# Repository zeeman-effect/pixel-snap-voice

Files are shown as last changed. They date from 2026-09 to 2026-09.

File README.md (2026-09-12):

# pixel-snap-voice

A one-off slim rectangular **voice-note recorder** that snaps to the back of a **Google Pixel 10** using Pixelsnap / Qi2 magnets (MagSafe-style accessory rings work). It records raw WAV files, charges and dumps data over USB-C, and leaves transcription to a computer.

This repo holds hardware, firmware, simulation, and (later) a local transcription helper. The first board is meant to be ordered from quick-turn services after the sims pass — not invented from unsolved problems.

## What it is

- ESP32-S3-MINI-1U, **ES8311 codec** (I2S master), analog MEMS mic, class-D speaker (or headphone jack if thickness loses)
- 16-bit PCM WAV, **48 kHz** mono (~173 MB/hour)
- USB Mass Storage when plugged into a computer
- No on-device transcription, no Wi-Fi in v1, no wireless charging through the accessory

MCU choice and why we did **not** switch off Espressif: [`docs/audio-platform.md`](docs/audio-platform.md).

## Repo layout

| Path | Role |
| --- | --- |
| [`docs/architecture.md`](docs/architecture.md) | Electrical + mechanical constraints |
| [`docs/audio-platform.md`](docs/audio-platform.md) | Why ESP32-S3 + codec, not a different MCU |
| [`docs/bom.md`](docs/bom.md) | Living bill of materials |
| [`docs/manufacturing.md`](docs/manufacturing.md) | JLCPCB / print / CNC |
| [`docs/phase0-bringup.md`](docs/phase0-bringup.md) | Off-the-shelf DevKit path before a custom PCB |
| [`firmware/`](firmware/) | ESP-IDF app + portable recorder/WAV core |
| [`sim/host/`](sim/host/) | `HOST_SIM` HAL, tests, PC WAV fixture |
| [`sim/spice/`](sim/spice/) | USB → charger → battery → 3.3 V model |
| [`hardware/cad/`](hardware/cad/) | Parametric envelope (OpenSCAD) + keepout checker |
| [`hardware/kicad/`](hardware/kicad/) | KiCad 10 schematic / PCB / stackup notes |
| [`.cursor/skills/`](.cursor/skills/) | Agent skills, including vendored [KiStack](https://github.com/American-Embedded/kistack) KiCad workflows |
| [`software/`](software/) | Local whisper.cpp CLI (`transcribe.py`) |

## Simulate first

From the repo root, with CMake and a C compiler (MSVC, MinGW, or clang):

```bash
cmake -S sim/host -B build/host
cmake --build build/host
./build/host/recorder_test      # Windows: build/host/Debug/recorder_test.exe
./build/host/recorder_sim
```

Mechanical keepouts (Python 3, no extra packages):

```bash
python hardware/cad/check_envelope.py
```

Power path (needs [ngspice](https://ngspice.sourceforge.io/)):

```bash
ngspice -b sim/spice/power_path.cir
```

## Physical phases

0. Prove capture **and playback** on an Espressif voice board (Korvo-2 / ESP-BOX) or OpenMic; Sense is recorder-core only. See [`docs/phase0-bringup.md`](docs/phase0-bringup.md).
1. Custom slim PCB + 3D-printed chassis + bought magnet ring (JLCPCB).
2. Same PCB in CNC **6061 aluminum** (not steel).

After you change the product schematic sources, run `python hardware/kicad/recorder/generate_recorder.py` then `python hardware/kicad/recorder/verify_schematic.py`. That overwrites sheets only. It does not write `recorder.kicad_pcb`. Edit the board (or rebuild it on purpose with `generate_pcb.py`) until traces and DRC are clean. Do not order boards until `python scripts/check_gates.py` is clean **and** `kicad-cli pcb drc` is clean **and** `kicad-cli` has written Gerbers from `hardware/kicad/recorder/recorder.kicad_pcb`.

## Transcription

Dump WAVs over USB, then run a local model (whisper.cpp) on the computer:

```bash
python software/transcribe.py /path/to/recordings/20260828-181742.wav
```

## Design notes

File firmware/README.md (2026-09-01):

# Firmware

Portable recorder core in `core/` plus an ESP-IDF app that runs on:

| Board | Capture | Playback | SD | Notes |
| --- | --- | --- | --- | --- |
| ESP32-S3-Korvo-2 | ES7210 mics | ES8311 + NS4150 | 1-bit SDMMC | Phase 0 default. I2S clocks follow Espressif (S3 master). |
| ESP-BOX / BOX-3 | ES7210 | ES8311 + PA | none on the main unit | Use Korvo if you need on-board SD. |
| Custom PCB | ES8311 ADC | ES8311 DAC + NS4150 | 4-bit SDMMC | Codec is I2S master (12.288 MHz oscillator → MCLK). Pin map: `hardware/kicad/pinmap.md`. |

## Buttons

- **Short press** — start or stop a recording (`/recordings/YYYYMMDD-HHMMSS.wav`, 48 kHz 16-bit mono PCM)
- **Double press** — play the last file (press again to stop)
- **Long press (~1.5 s)** — deep sleep; wake on the same button (custom PCB)

A host MSC mount wins. Record and play stop, TinyUSB owns the card, no new recordings until unmount. 5 V on VBUS is not that event. Phase 0 with MSC off, or no card, keeps recording on USB power.

## Time

The S3 RTC resets on battery pull. After a USB dump, put `set_time.txt` at the volume root with one line, UTC `YYYY-MM-DD HH:MM:SS`:

```
2026-08-28 18:30:00
```

The app applies it on boot and after USB unmount, then deletes the file.

## Build

ESP-IDF v5.1 or newer (`esp_codec_dev` + TinyUSB):

```bash
cd firmware
idf.py set-target esp32s3
idf.py menuconfig   # Pixel Snap Voice → board
idf.py build
idf.py -p COMx flash monitor
```

Disable `CONFIG_PSV_USB_MSC` if you only want an SD reader for Phase 0.

Host-side tests (no IDF):

```bash
cmake -S sim/host -B build/host
cmake --build build/host
```

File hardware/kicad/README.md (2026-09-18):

# KiCad — custom slim PCB

4-layer **0.8 mm**, ENIG. Origin = magnet-ring center (same as CAD). USB is full speed and deliberately **not** impedance controlled — see [Stackup](#stackup-jlc-4-layer-08-mm).

Two trees only:

- **Product:** `recorder/` — schematic + PCB. Open `recorder.kicad_pro`.
- **Learning:** `example_project/` — hand-made KiCad 10 sandbox. Not product truth. Leave it alone unless you are in that lesson.

```bash
python hardware/kicad/recorder/generate_recorder.py
python hardware/kicad/recorder/verify_schematic.py
python hardware/kicad/recorder/route_pcb.py --planes-only   # needs pcbnew
python scripts/check_gates.py
```

`route_pcb.py` and `generate_pcb.py` need an interpreter that can `import pcbnew`. On Linux that is the system `python3`; on Windows use `%LOCALAPPDATA%\Programs\KiCad\10.0\bin\python.exe`.

`generate_recorder.py` overwrites the recorder sheets. It does not write `recorder.kicad_pcb`. `route_pcb.py --planes-only` loads that board and pours copper. It does not move parts. Close the recorder project in KiCad before running either script.

`generate_pcb.py` rebuilds the board from scratch and wipes copper. Run it only when you intend a placement reset, then pour and route again. `route_pcb.py` with no flag does the whole job: it clears copper, lays the planes, hand-routes the parts an autorouter cannot do (the USB-C escape, the D+/D− pair, the fine-pitch fanouts), locks them, hands the rest to freerouting over Specctra DSN/SES, then pours, stitches and repairs until `kicad-cli pcb drc` is clean. Footprint XY: [`recorder/placement.json`](recorder/placement.json). Keep it in sync with the board. CAD envelope is `hardware/cad/params.json` + `case.scad`. Those numbers can move when the case or board moves.

`check_gates.py` checks the files that are already on disk. It does not regenerate.

Sheets: `mcu_usb`, `audio`, `power`, `io` (global labels join them). Pin map: [`pinmap.md`](pinmap.md).

Before a fab upload, land patterns must be datasheet footprints, `kicad-cli pcb drc` must be clean, and `kicad-cli` must write `fab/` from `recorder.kicad_pcb`. `check_gates.py` now does the last two itself. SP1 is the KELIKING KLJ-01304T-08R07W land in `PSV.pretty`.

## Design rules

The board is checked against JLCPCB's published standard 4-layer FR-4 capability rather than a set of house numbers, so a green DRC means the fab can build it. Global floors are `DESIGN_RULES` in [`recorder/generate_pcb.py`](recorder/generate_pcb.py); each entry names the JLC figure it comes from and says where it is deliberately tighter. Two checks depend on what kind of item is involved and cannot be a single global minimum, so they live in [`recorder/recorder.kicad_dru`](recorder/recorder.kicad_dru): pad hole-to-hole spacing at 0.6 mm (JLC's floor is 0.45 mm; 0.6 mm keeps the plated-hole tolerance) and minimum non-plated hole (0.5 mm).

What the board actually holds, against what JLC allows:

| | Board | JLC standard |
| --- | --- | --- |
| Track width | 0.15 mm | 0.1016 mm |
| Via | 0.6 mm on a 0.3 mm drill | 0.25 mm on 0.15 mm |
| Pad hole-to-hole | 0.62 mm | 0.45 mm |
| Via hole-to-hole | 0.30 mm | 0.20 mm |
| Hole to copper | 0.30 mm | 0.20 mm |
| Copper to routed edge | 0.30 mm | 0.20 mm |
| Silk text | 1.0 mm on a 0.15 mm stroke | 1.0 mm on 0.15 mm |

Hole-to-copper is held at 0.3 mm rather than JLC's 0.2 mm because non-plated holes carry a ±0.2 mm diameter tolerance: a 1.7 mm mounting hole can come back 0.1 mm larger in radius and eat the difference. The same margin is what forced MK1's ring pad outward, since the stock Infineon land leaves only 0.18 mm to the sound port.

## Stackup (JLC 4-layer 0.8 mm)

| Layer | Role | Copper |
| --- | --- | --- |
| F.Cu | signals, tall parts (battery side) | 1 oz |
| prepreg | ~0.10 mm | |
| In1.Cu | GND plane | 0.5 oz |
| core | ~0.53 mm | |
| In2.Cu | **VDD33** pour | 0.5 oz |
| prepreg | ~0.10 mm | |
| B.Cu | GND, **flat toward the shunt / phone** | 1 oz |

USB pair: 0.20 mm traces on a 0.40 mm pitch, F.Cu over the solid In1 GND plane. **Not impedance controlled, and no controlled-impedance option needs ordering.** The ESP32-S3 USB peripheral is full speed only (12 Mbps, no high-speed PHY), and 90 Ω on this 0.1 mm top prepreg would need roughly 0.06 mm traces, half what a quick-turn fab will run. The geometry above lands near 75 Ω differential by first-order microstrip, which is fine at full-speed edge rates. If a later revision ever needs high-speed USB, thicken the top prepreg first.

The pair is long for USB. That is placement, not sloppiness: U1's USB pads sit on the module's top row, the far side of a 15.9 mm module from J2, and the castellations leave 0.05 mm between pads, so the pair has to go around the module rather than under it. It runs up the 3.3 mm channel between J1 and U1. The millimetres used to be typed here too. They are measured off the board by `route_pcb.py` and written to [`recorder/placement.json`](recorder/placement.json) under `routing.usb`; read them there, because a copy in prose goes stale the first time anyone reroutes.

## Keepouts

- No tall parts on B.Cu (phone / shunt side)
- Mic on the right long edge, away from U4 / U5
- USB-C (**J2**) on the bottom short edge, offset +8 mm
- JST-PH battery (**BT1**) on the top-left, land `JST_PH_S2B-PH-K`. USB-C is the only 5 V inlet
- Analog island (U2, U8, MK1, Y1) off **VDD33**
- Analog footprint centres off the magnet circle; SP1 also by courtyard, because the 13 mm can holds a magnet (`check_placement.py`)
- PA LC away from the magnet circle (comment layer)
- MINI-1U module (15.4 × 15.4 mm). No PCB-antenna keepout. IPEX unpopulated
- 4× M1.6 holes. No fiducials on this first pass.

Gerbers: `fab/` after `scripts/check_gates.py`, which runs `kicad-cli pcb drc` first and then writes the Gerbers, both drill files, the pick-and-place CSV, `recorder-jlc.zip` and the JLCPCB CSVs (`jlcpcb_bom.csv`, `jlcpcb_cpl.csv`, `jlcpcb_extra.csv`, via [`recorder/generate_jlc.py`](recorder/generate_jlc.py)) in one pass from `recorder.kicad_pcb`. Do not hand-export or hand-edit only part of that set: a drill file that does not match the copper is a scrap board, and a pick-and-place row that does not match it is a misassembled one. Both CSVs were hand-kept until four decoupling capacitors were found still sitting at their pre-route coordinates. The gate runs DRC at every severity and with `--schematic-parity`, then runs it again with `--refill-zones` and refuses to plot if the answers differ — `kicad-cli` plots the fill stored in the board, so a stale pour would ship while DRC quietly refilled and passed it.

Open `recorder/recorder.kicad_pro` in KiCad 10. ERC/DRC in KiCad is the last human glance. The Python checks are the repo gate.

U1 comes from `hardware/cad/params.json` `mcu`. Change the module there, then update the recorder schematic sources and regenerate the sheets.

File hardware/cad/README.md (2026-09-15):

# CAD envelope

OpenSCAD and `params.json` must stay twins. `params.json` and `params.scad` share the same Pixel 10 + magnet-ring numbers. Change a number in both files. `check_envelope.py` fails if they drift, if the accessory hits a keepout, if the lid battery fence hits SP1 or U1, or if the speaker grille XY drifts from `placement.json` SP1.

```bash
python hardware/cad/check_envelope.py
openscad -o hardware/cad/case.stl hardware/cad/case.scad   # PETG
```

## Current defaults (caliper before CNC)

| Item | Value |
| --- | --- |
| Pixel 10 body | 152.8 × 72.0 × 8.6 mm |
| Camera bar | 24 mm from top, full width (measure) |
| Pixelsnap center | 85 mm from top, 36 mm from left (measure) |
| Magnet ring | OD 56 / ID 44 / 1.1 mm + 0.3 mm steel shunt |
| Accessory | 67 × 90 × 9 mm |
| PCB | 64 × 86 × 0.8 mm, 4-layer |

Print the magnet pocket slightly loose (`pocket_extra` in `case.scad`), shim, then tighten after the real ring arrives. Chassis is PETG first, 6061 later — not steel.

Shared origin, heights, and the PETG-on-Pixel checklist: [`INTERFACE.md`](INTERFACE.md).

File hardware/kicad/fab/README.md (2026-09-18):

# Fab export

`python scripts/check_gates.py` writes this whole folder from `hardware/kicad/recorder/recorder.kicad_pcb`, in one pass, after running `kicad-cli pcb drc`. It needs `kicad-cli`: on Linux that is on PATH, on Windows it is `%LOCALAPPDATA%\Programs\KiCad\10.0\bin\kicad-cli.exe`.

Contents: Gerbers, PTH/NPTH Excellon drills and their map PDFs, `recorder-pos.csv` (pick and place), and `recorder-jlc.zip`. The zip holds the copper, mask, silk, outline and drills only — the Fab, Courtyard, Adhesive, Margin and User layers are internal documentation and JLCPCB should not see them. BOM/CPL/extra sit one level up: `jlcpcb_bom.csv`, `jlcpcb_cpl.csv`, `jlcpcb_extra.csv`.

Never hand-export part of this set. These files only mean anything together: an earlier version of the gate script refreshed the Gerbers but left the drill file at whatever date it was committed with, which described a board with none of its vias drilled.

JLC order: 4-layer, 0.8 mm, ENIG. **No controlled impedance** — USB here is full speed and the pair is deliberately uncontrolled. Everything else is standard capability too: 0.15 mm minimum trace, 0.6 mm vias on a 0.3 mm drill, standard-font silkscreen. Nothing here should trigger a fine-line, small-via or high-precision-legend surcharge. See `hardware/kicad/README.md`.

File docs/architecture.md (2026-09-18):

# Architecture

One-off Pixelsnap-compatible voice recorder. Copy known ESP32-S3 + codec + LiPo + USB MSC patterns. Do not invent wireless charging through the shell or on-device ASR. MCU vs codec rationale: [`audio-platform.md`](audio-platform.md).

## System

```
Pixel 10 (Pixelsnap / Qi2 magnets)
        |
   magnet ring + steel shunt  (accessory side)
        |
  analog MEMS --> ES8311 ADC --I2S--> ESP32-S3 --FAT--> microSD
  speaker/HP  <-- ES8311 DAC + PA     |                    |
                         USB 2.0 device              USB MSC
                                |
                    USB-C 5 V sink + CC 5.1k
                                |
                         BQ24074 power-path
                           |           |
                         VSYS        VBAT (pouch)
                           |
                    3.3 V digital + 2.8 V analog LDO
```

ES8311 is the **I2S master** (12.288 MHz oscillator into MCLK). The S3 is slave. Analog AVDD for the codec and the MEMS mic is a separate 2.8 V LDO (U8 LP5907-2.8, net **3V3A**) from the MCU 3.3 V rail (U4 AP2112 + U5 AP22804, net **VDD33**). The analog rail is 2.8 V because IM73A135 VDD abs max is 3.0 V; ES8311 AVDD is 1.7–3.6 V. A buck is preferred for battery life; this spin uses the LDO.

When USB is plugged in: stop recording, expose `/recordings` as a USB Mass Storage volume, charge. When idle: deep sleep, button wake.

## Solved references

- Firmware / WAV-to-storage / USB mount: [ESP32-OpenMic](https://codeberg.org/RevK/ESP32-OpenMic)
- Early bring-up: ESP32-S3-Korvo-2 / ESP-BOX (ES8311 + analog mic + PA); Sense is recorder-core only
- Magnet geometry: MagSafe accessory array / Qi2 MPP ring (commodity rings), not a custom magnet design

## Electrical

| Block | Choice | Notes |
| --- | --- | --- |
| MCU | ESP32-S3-MINI-1U (≥8 MB flash) | Native USB. Same pins as MINI-1, 15.4 × 15.4 mm, no PCB antenna. **Not** the audio bottleneck. |
| Codec | Everest ES8311, I2S master, 12.288 MHz oscillator → MCLK | PGA/ALC/ADC + DAC + HP. Dedicated analog LDO (U8). No XI/XO on this codec. |
| Mic | Analog MEMS: IM73A135 (~73 dBA) | Pin 3 is OUT−, left open; C15 couples OUT+. VDD 2.8 V. Fallback: ICS-43434 I2S (65 dBA). **INMP441 is EOL.** |
| Playback | NS4150B into KELIKING KLJ-01304T-08R07W (13 mm SMD, LCSC C18186315) | 8 Ω 0.7 W can JLC can place. If 9 mm loses: 3.5 mm jack on ES8311 HP |
| Storage | Low-profile microSD (FAT32) | Switch to eMMC only if CAD proves SD is too thick |
| USB-C | 5 V sink only, 5.1 kΩ CC1/CC2 pulldowns, USB 2.0 | No USB-PD. USB-C is the only 5 V inlet |
| Charge | BQ24074RGTR, USB500 ~500 mA (EN1/EN2, ISET 1.8 kΩ) | Power-path: **VSYS** = OUT (loads), **VBAT** = pouch only. Charge LED on STAT. No fuel gauge |
| 3.3 V | Buck preferred (efficiency); LDO this spin (U4 AP2112 + U5 AP22804 → **VDD33**) | U4 VIN from **VSYS**. Keep the regulator and any later switching node away from the mic |
| Battery | Single-cell LiPo pouch on JST-PH BT1 | Size from leftover volume. Buy a protected 1S pouch; this board has no pack protector |
| Controls | 1 user tactile (SW1): short = record, double = play last, long = sleep. Two prototype flash buttons (SW_BOOT, SW_RST), lid-off only | 1 LED: record / play / charge / error |
| RF | MINI-1U IPEX, no cable in v1 | A PCB antenna would sit next to a steel shunt and later an aluminum shell. Wi-Fi off in firmware. |

### Audio format

- Container: WAV (RIFF)
- Encoding: PCM, 16-bit signed little-endian
- Rate / channels: **48 kHz**, mono (16 kHz sounds telephone-narrow on playback; codecs expect 48 k)
- Path: `/recordings/YYYYMMDD-HHMMSS.wav`
- Size: 48000 × 2 bytes/s = **96 kB/s ≈ 173 MB/hour** → ~46 hours on 8 GB
- Do not store 24-bit files; 16-bit already exceeds a 65–74 dBA capsule. Keep 24-bit on the I2S wire if the mic provides it.

### Power budget (v1 estimate)

MCU-only 126 mA was optimistic. With codec and SD, PA off, the working number is about 160 mA from the cell. Current pouch is **500 mAh** from leftover CAD volume (~3.1 h). Change the pouch if leftover volume or measured current changes. Re-measure on the SMT board. Idle deep-sleep is dominated by the charger IC and any always-on LDOs. Keep a true load switch on the 3.3 V rail.

### USB-C

- CC1 and CC2 each 5.1 kΩ to GND (UFP / sink)
- VBUS to charger IN through a PTC. USB-C is the only 5 V inlet.
- **BT1** is a JST-PH (`S2B-PH-K-S`, land `JST_PH_S2B-PH-K`) for a 1S pouch on VBAT. Do not put 5 V on BT1. Do not strap **VSYS** (charger OUT) to VBAT. C21 (10 µF) sits on VBAT next to U3 so BAT has local ceramic when BT1 is open.
- D+/D− to ESP32-S3 USB PHY (or USB-Serial/JTAG pins per module datasheet)
- Do not implement PD sink for v1

## Mechanical — Pixel 10 + Pixelsnap

Sources: GSMArena / Google store for body size; WPC Qi2 / MagSafe accessory practice for the ring. **Magnet center on the Pixel 10 must be calipered** before a metal shell is cut; CAD parameters live in [`hardware/cad/envelope.scad`](../hardware/cad/envelope.scad).

| Item | Value | Status |
| --- | --- | --- |
| Phone body | 152.8 × 72 × 8.6 mm | Published |
| Camera bar extra thickness | ~3.4 mm | Published (Pixel 9-class bar; confirm on device) |
| Camera bar length along height | parameterized, default 24 mm from top | **Measure** |
| Qi2 / MagSafe accessory ring | OD ~56 mm, ID ~44 mm, thick ~1.0–1.2 mm | Commodity part |
| MagSafe accessory array (Apple-style) | often OD 54 × ID 46 × 1.1 mm | Accept either; pocket to the part you buy |
| Steel shunt | thin plate **behind** the ring (away from the phone) | Required for hold strength |
| Accessory envelope (v1 target) | 67 × 90 × 9 mm | Current numbers in `hardware/cad/params.json`. Edit them if the case needs to move. |
| Pixelsnap center | 85 mm from top, 36 mm from left | **Caliper before CNC** |
| Chassis | 3D-print first; CNC **6061 aluminum** later | **Not steel** — steel shorts the magnetic path |

### Stack (phone glass → outside)

1. Magnet ring + adhesive
2. Steel shunt
3. PCB (MCU, codec, mic, PA, USB-C, SD)
4. LiPo pouch
5. Back shell (plastic proto / 6061)

### Keepouts (enforced by `hardware/cad/check_envelope.py`)

- Accessory outline must **not overlap the camera bar** in the XY plane when snapped.
- USB-C on a **short edge**; overmold keepout must not intersect the phone body.
- Mic acoustic port on a **free long edge**, not into the glass, or recordings go muffled.
- Magnet ring must stay inside the accessory outline.
- Analog codec island and mic bias stay off **VDD33**; PA LC/ferrite away from the magnet ring.

### Metal / magnets / OIS

Use an **aluminum or plastic** shell. Put ferromagnetic material only as the designed shunt behind the ring. The phone already expects a MagSafe-style ring at the Pixelsnap location; do not add extra magnets near the camera bar (OIS / magnetometer).

## Firmware split

Portable core (`firmware/core`) builds two ways:

- `HOST_SIM` — POSIX files, fixture WAV or generated PCM, tests in `sim/host`
- `ESP_PLATFORM` — ESP-IDF `app_main`, ES8311 duplex I2S (`esp_codec_dev`), SD, USB MSC, deep sleep

State machine: `IDLE` → `RECORDING` or `PLAYING` → `IDLE`. A host **MSC mount** forces `USB_MSC` (record and play stop). VBUS alone does not. No card, or `CONFIG_PSV_USB_MSC` off, means USB power does not take the card.

## Out of scope

- On-device transcription
- Wi-Fi
- Charging the phone through this accessory
- MagSafe / Qi2 certification
- Waterproofing
- Android app while snapped on (USB-OTG geometry is awkward)

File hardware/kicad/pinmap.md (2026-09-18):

# Custom PCB pin map

Human table. Matches `firmware/boards/custom.h` and `hardware/kicad/recorder/` refs.
Not generated. Origin and heights: [`../cad/INTERFACE.md`](../cad/INTERFACE.md). Footprint XY: [`recorder/placement.json`](recorder/placement.json).

U1 is ESP32-S3-MINI-1U-N8 (`params.json` `mcu`). ES8311 is I2S **master**; S3 is slave.
Y1 is a 12.288 MHz oscillator into ES8311 **MCLK**. The codec has no XI/XO pins.
Strapping GPIO0 / GPIO45 / GPIO46 are not used as I2S or SD.

## ESP32-S3-MINI-1U-N8

| GPIO | Net | Direction | Goes to |
| --- | --- | --- | --- |
| 3V3 / GND | **VDD33** / GND | power | U5 AP22804 / pour |
| GPIO19 / GPIO20 | USB_DM / USB_DP | USB PHY | U7 USBLC6-2, **J2** |
| GPIO4 / GPIO5 | I2C_SDA / I2C_SCL | open-drain | U2 ES8311 CDATA / CCLK |
| GPIO14 | I2S_MCLK | input | U2 MCLK + Y1 out |
| GPIO13 | I2S_BCLK | input | U2 BCLK |
| GPIO12 | I2S_WS | input | U2 LRCK |
| GPIO10 | I2S_DIN | input | U2 ASDOUT |
| GPIO11 | I2S_DOUT | output | U2 DSDIN |
| GPIO8 | PA_EN | output | U6 NS4150 CTRL |
| GPIO15 | SD_CLK | output | **J3** |
| GPIO7 | SD_CMD | bidirectional | **J3** |
| GPIO6 / 16 / 17 / 18 | SD_D0–D3 | bidirectional | **J3** 4-bit SDMMC |
| GPIO0 | BOOT | strapping, pull-up | SW_BOOT to GND (download, lid-off). Not a firmware button |
| GPIO1 | BTN | input, pull-up | SW1 to GND |
| GPIO2 | LED | output | D1 |
| GPIO9 | CHG_STAT | input | U3 STAT (D2 charge LED on this net) |
| GPIO43 / GPIO44 | UART_TX / UART_RX | UART0 | **J1** 1×4 (3V3, U0RXD, U0TXD, GND) |
| EN | EN | module enable | R1 10k / C2 plus **SW_RST** to GND |

## Other

| Net | Notes |
| --- | --- |
| CC1 / CC2 | R2 / R3 5.11 kΩ to GND (UFP) on J2 |
| **VDD33** | U4 AP2112 → U5 AP22804. MCU digital rail |
| 3V3A | U8 LP5907-2.8 from **VSYS** (~2.8 V); star return to AGND; no digital return through MK1. Named 3V3A; it is not 3.3 V |
| VBAT | LiPo pouch on BT1; U3 BQ24074 BAT plus C21 at the QFN. Do not strap to VSYS |
| VSYS | U3 OUT. USB or cell, whichever is up. Feeds U4, U8, U6 |
| RF | MINI-1U IPEX connector, no cable in v1 |

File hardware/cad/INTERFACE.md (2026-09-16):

# CAD ↔ PCB interface

One origin, one height map. If a number moves, change CAD and the board together. Do not leave a second copy only in KiCad.

## Origin

Phone-facing view of the accessory.

- **(0, 0)** = center of the magnet ring = Pixel Pixelsnap axis
- **+X** = phone right
- **+Y** = toward the camera bar (phone top)
- **+Z** = away from the glass (out of the phone)

The KiCad board origin matches. Edge.Cuts is the 64 × 86 mm PCB, not the 67 × 90 mm shell.

## Height map (phone glass → outside)

| Layer | Z span (mm) | Notes |
| --- | --- | --- |
| Adhesive | 0.00–0.15 | Ring stock / VHB, phone-facing |
| Magnet ring | 0.15–1.25 | Ferromagnetic only here + shunt |
| Steel shunt | 1.25–1.55 | Behind the ring, away from the phone |
| PCB | 1.55–2.35 | 0.8 mm; **B.Cu** is the flat phone-facing side |
| Tray / lid split | 2.35 | `tray_h` = adhesive + magnet + shunt + PCB = 2.35 mm. `lid_h` = 6.65 mm |
| Tall parts | 2.35–5.55 | USB-C 3.2 mm, module 2.4 mm, SD on **F.Cu**. In the lid |
| LiPo pocket | 2.35–7.35 | 5.0 mm pouch at (0, 10), +Y of U1/J2 and −Y of SP1 |
| Speaker (SP1) | 2.35–6.35 | 4.0 mm KELIKING can on F.Cu. Sound faces the lid |
| Back shell | 7.80–9.00 | 1.2 mm PETG (`shell_back`). `speaker_grille()` opens the skin over SP1 |

Envelope budget is **9.0 mm**. USB stack is 6.75 mm. Speaker stack is 7.55 mm. Battery stack is 8.55 mm.

`case.scad` puts a 0.4 mm PETG floor under the magnet ring so it cannot fall through. That floor is a print trick. It does not change the stack numbers in `params.json`. Edit those if the stack changes. After the real ring arrives, shim, then tighten the pocket.

The tray also leaves a 0.5 mm PETG floor on the phone face under MK1. A 3 mm collector under the B.Cu NPTH at (30.00, 9.32) and a 3 mm channel in +X take that hole out the right wall, where it joins `mic_port()`. MK1 is on F.Cu. A port that faces the glass muffles recordings. If you move MK1, move the duct and the wall hole with it.

SW_BOOT / SW_RST are 5.1 × 5.1 × 5.0 mm top-actuated parts on F.Cu. Lid cavity above the PCB is 5.45 mm, so the actuators sit 1.65 mm under the outer skin. **Lid-off only** this spin: a flush hole in 1.2 mm PETG does not reach them.

## XY locations (magnet-centered)

Edge features are the wall or board edge (PCB is 64 × 86 mm, so the long edges are ±32 mm and the short edges are ±43 mm). Footprint centers are inset.

The official board is `hardware/kicad/recorder/recorder.kicad_pcb`. Footprint XY lives in `hardware/kicad/recorder/placement.json`.

The table below is the CAD wall-cut contract from `params.json`. Change the case cuts when you move a part or caliper a phone and a stuffed board.

| Feature | X (mm) | Y (mm) | Max Z above PCB |
| --- | --- | --- | --- |
| USB-C edge / overmold | +8.0 | −45.0 (accessory bottom wall) | 3.2 mm (F.Cu) |
| USB-C footprint (J2) | +8.0 | −37.6 | 3.2 mm (F.Cu). Mouth at y=−43. Rectangular wall slot this pass |
| Mic port (wall) | +33.5 (right long wall) | +10.0 | 3 × 2 mm hole at the tray/lid split (`mic_port()`). Tray `mic_duct()` joins this hole. |
| Mic capsule (MK1) | +30.0 | +10.0 | IM73A135 on **F.Cu**, rot 90°. Bottom-port NPTH is at (30.00, 9.32) on **B.Cu**. Port must not face glass. The tray ducts that hole under the PCB to the right wall. |
| Button edge | −33.5 (left long wall) | +12.0 | 3 × 2.2 mm press-through slot (`button_hole()`). Needs a moulded nub to span the 0.9 mm from the inner wall face to the actuator tip. |
| Button (SW1) | −29.3 | +12.0 | side-actuated Panasonic EVQP7C01P, rot 270° so the actuator faces the left wall. Tip 0.6 mm inside the board edge; copper 1.46 mm off it. |
| LED (D1) | −29.0 | +18.0 | side window in the lid wall, not through the back |
| SD slot (J3) | see placement.json |  | no mouth in this pass |
| Speaker (SP1) | 0.0 | +36.0 | 4.0 mm KELIKING KLJ-01304T on F.Cu. Sound faces the lid; `speaker_grille()` opens the back skin |
| JST-PH (BT1) | −23.5 | +34.0 | S2B-PH-K-S, 6.0 mm tall. Pad 1 (VBAT) at this XY; cable toward y=+43. `jst_window()` cuts shell_back over the housing |
| LiPo pocket | 0.0 | +10.0 | 40 × 30 × 5 mm pouch. Lid `battery_fence()` outer is 43.6 × 33.6 mm around this. Was y=12; that put the +Y wall 0.7 mm from SP1. |
| MCU module (U1) | +14.0 | −18.0 | 2.4 mm, next to USB; MINI-1U, IPEX unused |
| Mounting holes | ±(32−3.5), ±(43−3.5) | M1.6 clearance |

### Recorder designators

These are the recorder project names. Do not keep the old generated-board map.

| Ref | What |
| --- | --- |
| J2 | USB-C receptacle |
| J3 | microSD |
| J1 | UART header |
| U8 | analog LDO (codec / mic) |
| VDD33 | MCU 3.3 V rail |
| U1 | ESP32-S3-MINI-1U |
| BT1 | JST-PH S2B-PH-K-S (pad 1 at −23.5, 34) |

Export KiCad STEP (`File → Export → STEP`) and import next to `case.scad` (OpenSCAD cannot import STEP; use the STL from `case.scad` plus the KiCad 3D view, or Fusion/Onshape for a boolean). `check_envelope.py` is the automated gate; a 3D collision pass is visual.

## PETG print fit on a Pixel 10

`case.scad` already lays the two parts on one plate: tray at the origin, lid shifted +X.

1. Print in PETG. Tray sits phone-face down. Lid sits mating-face down (the rabbet groove is on the bed).
2. Magnet pocket is 0.3 mm loose on OD. Drop in the bought ring + steel shunt (shunt **behind** the ring, away from the phone). Shim with tape. Do not chase a tight magnet until the real ring is on the desk. Isolate the shunt from any later metal lid with tape.
3. M1.6 screws. `hole_d` 1.7 mm and the boss bore are **clearance**, not a tap. Do not thread PETG. Nuts or heat-set inserts come later. Keep screw heads off the phone glass.
4. Drop in a dummy PCB (or the first fab) and a 5 mm dummy pouch. The pouch pocket is 40 × 30 × 5 mm at (0, 10), clear of U1, J2 and SP1. Confirm the lid grille sits over the speaker and the fence wall does not hit the can.
5. Snap to the Pixel. Confirm:
   - camera bar not covered
   - USB-C cable overmold misses the phone
   - mic port is on the long edge, not against glass
   - button reachable while snapped
   - snap hold feels OK (add or remove tape shims)
   - tray and lid still locate on the lip after a few open/close cycles
6. Only then order SMT, or order PCB+SMT in parallel if this 3D check is clean and you accept a spin.

Assembly order: ring adhesive on glass side → ring → shunt → PCB (flat to shunt) → pouch → lid. Screws plus the mating lip hold it. No snap-fit this pass.

Pixel body and Pixelsnap center stay the published defaults until you caliper a real phone. **Caliper before any 6061 toolpath.** Chassis is PETG first, then 6061, never steel.

## If 9 mm loses

SP1 is a 4.0 mm SMD can. The speaker stack is 7.55 mm under a 9.0 mm envelope. If a stuffed board still blows the stack, use the ES8311 3.5 mm jack and drop the PA. That decision belongs at this height-stack check, not after fab.

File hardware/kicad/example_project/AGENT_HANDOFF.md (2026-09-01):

# Learning schematic handoff

Continue a supervised KiCad 10 schematic lesson. Zach is drawing `hardware/kicad/example_project` by hand to compare later with `hardware/kicad/recorder/`. He does the edits. You review, correct, and give **one** next step. Do not make large unsupervised edits. Fix a section only when he asks.

This file is the brief. Do not load the full prior chat.

## Overrides

Workspace rule says do not edit `example_project`. **This lesson overrides that.** You may read and, with his OK, make small fixes there.

Do **not** edit the product tree `hardware/kicad/recorder/` as part of this lesson. Compare his sheet to `recorder/` for refs and nets. Do not treat `recorder/` as a pin-for-pin copy-paste template. Architecture truth: `docs/architecture.md`, `docs/audio-platform.md`, `docs/bom.md`, `hardware/kicad/pinmap.md`, `hardware/cad/params.json` (`mcu` = ESP32-S3-MINI-1U-N8, no radio, no PCB antenna).

v1: USB recorder, 5 V sink only, no OTG host, no PD, no Wi-Fi.

Be brief. Plain language. Define a term once. Conserve chat context: review the `.kicad_sch` (or `.history` if newer) instead of dumping sheets into the thread.

## How he works

- KiCad 10. Schematic: `hardware/kicad/example_project/example_project.kicad_sch`
- **Toolbar Save works. Ctrl+S often does not.** Check Hotkeys → Save. Local history (`.history/example_project.kicad_sch`) can be newer than the project file. If the repo file looks stale, read history and tell him to Save.
- `Q` is Place → no-connection flag, not a symbol named Q.
- Net labels (`L`) name a net only if they sit on a wire. Generic connector pin names are hidden in the library; he cannot rename `Pin_1` from properties.
- Power symbol **Value** is the net name (`VDD33`, `VBUS`, `VBUS_CHG`, `VBAT`). `Earth` ≠ `GND`.
- ERC `pin_not_connected` on unused GPIOs is expected. Do not `Q` pins he will use later (I2C, I2S, SD, button, LED).
- ERC `power_pin_not_driven` on named rails is expected until a regulator or `PWR_FLAG` exists. Do not fake-fix with `PWR_FLAG` unless you are teaching that on purpose.

## What is on the sheet (as of 2026-08-30)

**MCU**

- U1 `ESP32-S3-MINI-1` symbol, value `ESP32-S3-MINI-1U`, footprint `PCM_Espressif:ESP32-S3-MINI-1U`. Correct pairing (same pins, IPEX on module).
- Pin 3 `3V3` → `VDD33`. Stacked GND → `GND`.
- EN RC: R1 `10K`, C2 `1 µF` (datasheet §9 / Fig 9-1).
- C1 `22 µF` + C3 `0.1 µF` on `VDD33`.
- J1 UART 1×4: pin1 `3V3`, pin2 U0RXD (GPIO44), pin3 U0TXD (GPIO43), pin4 `GND`. Labels `UART_TX` / `UART_RX` plus adapter TX/RX notes. MCU TX → adapter RX.

**USB-C (J2)**

- `Connector:USB_C_Receptacle_USB2.0_16P` (keep 16P; 14P drops SBU only). Not a Plug.
- GPIO20 → D+ (A6 shorted to B6). GPIO19 → D− (A7 shorted to B7). Labels `USB_DP` / `USB_DM` on the wires (~x=233).
- CC1 and CC2 each have their own `5.11k` (R2, R3) to `GND`. Not tied together.
- SBU1 / SBU2 unused. Shield still open (OK).
- Do **not** copy Fig 9-1 OTG (no ID pin, no host VBUS out). USB-C role is CC pulldowns.

**5 V / charger** (confirmed with `kicad-cli sch export netlist`, not raw coordinates)

- J2 A4/A9/B4/B9 VBUS → F1 pin 2. F1 pin 1 → `VBUS_CHG` → C4 pin 1 and U2 pin 4 `V_{DD}`.
- U2 `MCP73831-2-OT` (BOM U3 / `MCP73831T-2ACI/OT`). VSS pin 2 → `GND`. PROG pin 5 → R4 `2k` → `GND`.
- C4 `4.7 µF` on `VBUS_CHG` to `GND`. C5 `4.7 µF` on `+BATT` to `GND`.
- The old short at `(250.19, 44.45)`–`(250.19, 48.26)` is gone. `+BATT` ≠ `VBUS_CHG`.
- `#PWR010` is `power:+BATT`, Value `+BATT`. That net is U2 pin 3 `V_{BAT}` + C5. Electrically right. Rename Value to `VBAT` so the rail matches the lesson names.
- STAT pin 1 is open. ERC `pin_not_connected` at `(276.86, 58.42)`. Put `Q` until the LED.

Do not infer U2 pin nets from file coordinates. `kicad-cli` is `%LOCALAPPDATA%\Programs\KiCad\10.0\bin\kicad-cli.exe`.

## Open defect

None that blocks new parts. Optional cleanup: Value `+BATT` → `VBAT`, and `Q` on STAT.

## Suggested next steps (one at a time)

1. Rename `+BATT` to `VBAT`, `Q` on STAT. Then the 2-pin battery connector: `VBAT` and `GND`. Not to `VDD33`.
2. Battery connector (2-pin): `VBAT` and `GND`. Not to `VDD33`.
3. MCU 3.3 V LDO (BOM U4 `AP2112K-3.3`): VIN from `VBAT` (through load switch later), VOUT = `VDD33`. This clears the “magic 3V3” rail. Do not feed the LDO from raw VBUS.
4. Load switch (BOM U5 AP22804) on 3.3 V if you want sleep current next.
5. USB ESD `USBLC6-2SC6` on D+/D−, or analog 3V3A LDO (recorder: U8 LP5907), then ES8311. Codec is I2S **master**, 12.288 MHz oscillator into MCLK. Pin map: `hardware/kicad/pinmap.md`.
6. Leave IPEX unused (no cable in v1).

Do not start the codec until `VDD33` is generated from `VBAT` and the three rails stay separate: **5 V USB / ~4.2 V cell / 3.3 V MCU**.

## KiCad facts he already hit

- MINI-1 vs MINI-1U: same pin table. 1U is IPEX, no board antenna pin.
- Table 3-1: pin 3 only `3V3`; many stacked GND; EN must not float; USB_D− = GPIO19, USB_D+ = GPIO20. S3 PHY, no 22 Ω series.
- 16P has separate A6/B6 and A7/B7. Short same-name pairs or a flipped cable has no data.
- MCP73831 needs ≥4.7 µF on VDD and on VBAT.

## Style

Review what he drew. Name concrete nets and pins. One next action. No recorder-sheet copy-paste. No large refactors.

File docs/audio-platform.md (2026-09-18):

# Audio platform (MCU + codec)

**Current pick is the ESP32-S3.** Pair it with a real codec and a better capsule. Switching MCU throws away USB-MSC + ESP-IDF already in this repo and does not raise capsule SNR. Do it only if leaving Espressif is a hard requirement.

The S3 is not the hiss or the missing speaker. The original BOM recorded from a ~65 dBA digital MEMS and had **no DAC or amp**. nRF, STM32, RP2350, and i.MX RT cannot raise ICS-43434 SNR, and they throw away USB-MSC + ESP-IDF already in this repo.

## Bottlenecks (in order)

1. **No playback path** — MEMS → I2S → MCU cannot drive a speaker or headphone.
2. **The microphone’s own ADC** — [ICS-43434](https://cdn.sparkfun.com/assets/a/9/c/9/1/DS-000069-ICS-43434-v1.2.pdf) is 65 dBA SNR. The converter lives in the capsule.
3. **Power / layout** — analog mics and codec ADCs die if they share a noisy 3.3 V buck. Give the codec a dedicated analog LDO.
4. **ESP32-S3 has no APLL** — 48 kHz from the 160 MHz PLL is slightly inexact. Fix: **ES8311 is I2S master** with a 12.288 MHz oscillator into MCLK; the S3 is slave. ~0.1% pitch error is inaudible for voice notes. The codec has no XI/XO pins.

USB full-speed is enough to dump 48 kHz / 16-bit mono (~96 kB/s). Wi-Fi stays off. Use the MINI-1U module (IPEX, no cable), not the MINI-1 PCB-antenna sibling. The antenna keepout and extra 5.1 mm of module length buy nothing on a radio-off board that sits on a steel shunt.

This product already exists: [ESP32-OpenMic](https://codeberg.org/RevK/ESP32-OpenMic) (S3 module + ICS-43434 + MAX98357A + USB MSC). Espressif voice boards use **ES8311 + analog mic + class-D**, not a different SoC: [ESP32-S3-Korvo-2](https://docs.espressif.com/projects/esp-adf/en/latest/design-guide/dev-boards/user-guide-esp32-s3-korvo-2.html), IDF [`i2s_es8311`](https://docs.espressif.com/projects/esp-idf/en/stable/esp32s3/api-reference/peripherals/i2s.html), [`esp_codec_dev`](https://components.espressif.com/components/espressif/esp_codec_dev).

## Default (v1 custom PCB)

ESP32-S3-MINI-1U + **ES8311 as I2S master** (12.288 MHz oscillator → MCLK) + analog MEMS (**IM73A135**, ~73 dBA, 2.8 V VDD) + **NS4150B** into a KELIKING KLJ-01304T-08R07W (13 mm SMD can, LCSC C18186315), or ES8311 headphone jack if 9 mm loses.

**Fallback:** ICS-43434 into the S3 or ES8311 digital-mic pin (capture stays 65 dBA; playback still good).

Record **48 kHz, 16-bit, mono PCM WAV**. Keep 24-bit on the I2S wire if the mic provides it; store 16-bit files. whisper.cpp will resample. ~173 MB/hour.

## Ranked options

| Rank | Architecture | When |
| --- | --- | --- |
| 1 | S3-MINI-1U + ES8311 + analog MEMS + class-D / HP | Default |
| 2 | S3-MINI-1U + ICS-43434 + MAX98357A (copy OpenMic) | Fastest; dictaphone-grade capture |
| 3 | i.MX RT1010 LQFP-80 + WM8960 | Only if leaving Espressif is a hard requirement — USB HS, full firmware rewrite, no capture-SNR win |

## Families we are not using

| Family | Why it loses here |
| --- | --- |
| nRF54L | No USB on the SoC |
| nRF5340 | USB FS exists, but aQFN + Zephyr rewrite; Audio DK is LE Audio, not a recorder |
| STM32 U5/H7 | SAI + codec is fine; Cube USB-MSC rewrite for no SNR gain |
| RP2040/RP2350 | Easy PCB; USB↔I2S clock pain; no better mic |
| ESP32-P4 | USB HS unused for file dump; larger module |
| Allwinner / Rockchip | Linux + DDR + PMIC; will not fit a 9 mm wallet |
| ADAU / SHARC | DSP without USB MSC |

A 100 dB codec ADC cannot invent capsule SNR. The codec **does** buy PGA/ALC, analog-mic option, headphone, and a clean clock master.

## Firmware delta (stay on ESP-IDF)

Add `esp_codec_dev` ES8311 duplex I2S. WAV writer already parameterized via `PSV_SAMPLE_RATE_HZ`. USB MSC unchanged. Phase 0 should use a Korvo-2 / ESP-BOX / OpenMic-class board to prove playback, not Sense-only PDM.

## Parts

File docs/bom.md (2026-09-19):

# Bill of materials (living)

Quantities are for **one** device plus a few passives of margin. Prefer JLCPCB SMT / LCSC Basic. Do not design around **INMP441** (EOL).

LCSC numbers below were captured from the public catalog (Sep 2026). Re-check stock and Basic vs Extended before the SMT order.

The LCSC column of the tables below is the only place order codes are typed. `hardware/kicad/recorder/generate_jlc.py` reads it, joins it to `recorder.kicad_pcb`, and writes `hardware/kicad/jlcpcb_bom.csv`, `jlcpcb_cpl.csv`, and `jlcpcb_extra.csv` during `python scripts/check_gates.py`. A board part on the assembly BOM with no number fails that script: JLCPCB will not machine-place an empty cell. Do not hand-edit those CSVs — put the number here and re-run the gates.

BT1 is through-hole, so it stays out of the pick-and-place file. It still needs an LCSC number: JLC wave-solders it from the assembly BOM. J1 is also through-hole, but it is flagged `exclude_from_bom`: the vertical header will not fit under the lid and the tails poke toward the phone. Keep C124378 in this table so `jlcpcb_extra.csv` still lists it — add that row under Extra Parts in the JLCPCB cart (shipped loose, not soldered) and hand-solder a header at bring-up if you need UART0. Mounting holes are mechanical and stay off all three files.

## Electrical

| Ref | Function | MPN | LCSC | Package | Notes | SMT |
| --- | --- | --- | --- | --- | --- | --- |
| U1 | MCU module | ESP32-S3-MINI-1U-N8 | C2980299 | 15.4 × 15.4 × 2.4 mm | Native USB; 8 MB flash; IPEX unpopulated | Extended |
| U2 | Audio codec | ES8311 | C962342 | QFN-20 3×3 | I2S master; 12.288 MHz oscillator into MCLK; analog island. No XI/XO | Extended |
| Y1 | Codec oscillator | Y322512.288MNCCZ | C49207908 | 3225 4-pin | JLYE CMOS oscillator into ES8311 MCLK; S3 is I2S slave. 1.8–3.3 V, same pinout as the Abracon ASE land (1=OE, 2=GND, 3=OUT, 4=VDD). OE and VDD are on **3V3A** (2.8 V). Not a crystal. Replaces Kyocera `C1857159`, a JLC SMT shortfall. Do **not** substitute a 3.3 V-only can such as Lucki `C5917271` (2.97 V min) | Extended |
| U8 | Analog LDO | LP5907MFX-2.8/NOPB | C186700 | SOT-23-5 | Dedicated 2.8 V (**3V3A**) for AVDD + mic + Y1. Do **not** share **VDD33**. IM73A135 VDD abs max is 3.0 V (typ 2.75 V); ES8311 AVDD is 1.7–3.6 V so 2.8 V is legal on both. Same SOT-23-5 pinout as the 3.3 V SKU. TI part, JLC Extended | Extended |
| U4 | MCU 3.3 V | AP2112K-3.3TRG1 | C51118 | SOT-25 | First spin LDO (buck preferred later). VIN from **VSYS** | Basic |
| U5 | Load switch | AP22804AW5-7 | C3001659 | SOT-25 | Switches U4 out onto **VDD33**; cuts sleep current | Extended |
| MK1 | Analog MEMS | IM73A135V01XTSA1 | C3171831 | LLGA-5 4×3 | ~73 dBA. Infineon: 1=OUT+ 2=VDD 3=OUT− 4=GND 5=GND. Single-ended: C15 couples OUT+; OUT− is open; codec MIC_N via C16 to AGND. VDD is 2.8 V (**3V3A**). JLC Extended SMT (they flag assembly as High). Acoustic port on the free long edge | Extended |
| MK1 alt | Digital MEMS | ICS-43434 | C5656610 | 3.5 × 2.65 | 65 dBA fallback if analog capsule misses SMT | Extended |
| U6 | Class-D PA | NS4150B | C189961 | MSOP-8 | Analog-in from ES8311 AOUT (Korvo path). VCC from **VSYS**. Alt: MAX98357A I2S | Extended |
| SP1 | Speaker | KLJ-01304T-08R07W | C18186315 | 13 × 13 × 4.0 | KELIKING 8 Ω 0.7 W SMD can. JLC Extended, tape-and-reel. Sound faces the lid | Extended |
| U3 | Li-ion charger | BQ24074RGTR | C54313 | VQFN-16 3×3 | Power-path. USB 500 mA (EN1/EN2), ISET 1.8 kΩ ≈ 500 mA. OUT = **VSYS**; BAT = pouch only. JLC Extended | Extended |
| J1 | UART 1×4 | B-2100S04P-A110 | C124378 | 2.54 mm 1×4 THT | Vertical 1×4. 3V3, U0RXD (adapter TX), U0TXD (adapter RX), GND. **Do not assemble**: 8.54 mm tall in a ~5.45 mm lid cavity, tails poke B.Cu toward the phone, no UART window in the case. Keep the LCSC so JLC can ship it as extra parts; hand-solder at bring-up | Extra |
| J2 | USB-C receptacle | 16-pin mid-mount | C165948 | ~3.2 mm | 5.1 kΩ on CC1/CC2; short edge; overmold must miss the phone | Extended |
| J3 | microSD socket | TF-01 / equivalent | C91145 | low-profile | 4-bit SDMMC on the custom PCB | Basic/Ext |
| U7 | USB ESD | USBLC6-2SC6 | C7519 | SOT-23-6 | Next to J2 on D+/D−. ST part; `C8678` is an SS34 SMA Schottky, not this chip | Extended |
| BT1 | 1S battery connector | S2B-PH-K-S | C173752 | JST-PH 2.0 mm THT | Side-entry. Plug a protected 1S pouch (PHR-2). USB-C runs the board with BT1 open. JLC wave-solders; not in the CPL | Wave |
| SW1 | Record button | Panasonic EVQP7C01P | C388883 | 3.5 × 2.9 × 1.35 mm | **Side push**: the plunger fires sideways at the left wall, so nothing has to poke through the phone-facing face. SPST, 2.2 N, 0.2 mm travel, 100k cycles, reflow. Short = record, long = power. Two moulded bosses drop into NPTH holes and take the sideways load off the solder. Was listed here as "side-fire, C318885": that code is an XKB TS-1187A-C-J-B, a 5.1 × 5.1 × 5 mm **top-actuated** switch, so the line was wrong on both the part and the direction | Extended |
| SW_BOOT / SW_RST | Boot / Reset | XKB TS-1187A-C-J-B | C318885 | 5.1 × 5.1 × 5 mm | Top-actuated SPST for prototype download. Hold Boot, tap Reset, release Boot. They strap GPIO0 and EN to GND; they are not firmware buttons. **Lid-off only** this spin | Extended |
| D1 | Status LED | 0603 red | C2286 | 0603 | Record / error (GPIO2) | Basic |
| D2 | Charge LED | 0603 | C2286 | 0603 | On U3 STAT / **CHG_STAT** | Basic |
| R2 / R3 | CC pulldowns | 0603WAF5101T5E | C23186 | 0603 5.1 kΩ 1% | USB-C UFP Rd on J2. Schematic value is 5.11 kΩ; this Basic part is 5.1 kΩ (the Type-C number) | Basic |
| F1 | VBUS PTC | BSMD0603-050-6V | C883095 | 0603 | 500 mA hold, 6 V, 1 A trip. Between VBUS and charger. `C37010` was a dead LCSC number, so JLC showed F1 as No Part Selected | Extended |
| MAG1 | Magnet ring | Qi2 / MagSafe accessory | — | OD 56 / ID 44 / 1.1 mm | Buy; do not machine. Pocket to the part you receive | — |
| SH1 | Steel shunt | thin plate | — | ~0.3 mm | **Behind** MAG1, away from the phone. Not the outer chassis | — |

## Passives

Same column order as **Electrical**, so `generate_jlc.py` can read the LCSC codes. Values and packages match the schematic. Ceramics are X5R/X7R at ≥10 V so 5 V USB and 4.2 V on the pouch stay inside a sensible derating. Audio coupling is still X5R: a 1 µF C0G in 0603 is not a JLC Basic part.

| Ref | Function | MPN | LCSC | Package | Notes | SMT |
| --- | --- | --- | --- | --- | --- | --- |
| C1 | VDD33 bulk at U1 | CL21A226MAQNNNE | C45783 | 0805 22 µF 25 V X5R | 3.3 V rail | Basic |
| C2, C6, C9, C10, C11, C12, C13, C15, C16, C17, C18, C19 | 1 µF decouple / couple | CL10A105KB8NNNC | C15849 | 0603 1 µF 50 V X5R | Codec, mic, PA, LDOs | Basic |
| C3, C14 | 100 nF decouple | CC0603KRX7R9BB104 | C14663 | 0603 100 nF 50 V X7R | U1 and SD rail | Basic |
| C4, C5 | Charger IN / OUT | CL10A475KO8NNNC | C19666 | 0603 4.7 µF 16 V X5R | VBUS_CHG and VSYS next to U3 | Basic |
| C7 | U4 output | CL10A225KO8NNNC | C23630 | 0603 2.2 µF 16 V X5R | AP2112 typical app | Basic |
| C8, C20 | 10 µF bulk 0805 | CL21A106KAYNNNE | C15850 | 0805 10 µF 25 V X5R | C8 is VDD33 at U5; C20 is VBAT at the pouch | Basic |
| C21 | VBAT at U3 | CL10A106MA8NRNC | C96446 | 0603 10 µF 25 V X5R | Local ceramic when BT1 is open. 25 V so 4.2 V on the pouch keeps more capacitance than a 10 V part | Basic |
| R1, R7, R10, Rboot, Rsd0, Rsd1, Rsd2, Rsd3, Rsd4, Rstat | 10 kΩ | 0603WAF1002T5E | C25804 | 0603 10 kΩ 1% | EN, PA bias, TS, boot, SD, STAT pull-ups | Basic |
| R4 | Charger ISET | 0603WAF1801T5E | C4177 | 0603 1.8 kΩ 1% | ≈500 mA charge | Basic |
| R5 / R6 | I2C pull-ups | 0603WAF4701T5E | C23162 | 0603 4.7 kΩ 1% | SDA / SCL to **VDD33** | Basic |
| R8 / R11 | Charger ILIM / ITERM | 0603WAF3011T5E | C22991 | 0603 3.01 kΩ 1% | BQ24074 typical app. Extended; 3.00 kΩ Basic would move the current a hair | Extended |
| R9 | Charger TMR | 0603WAF4992T5E | C23184 | 0603 49.9 kΩ 1% | Fast-charge timer | Basic |
| Ragnd | AGND stitch | 0603WAF0000T5E | C21189 | 0603 0 Ω | Analog island to GND | Basic |
| Rchg / Rled | LED series | 0603WAF1001T5E | C21190 | 0603 1 kΩ 1% | D2 and D1 | Basic |

## Mechanical

| Item | Candidate | Notes |
| --- | --- | --- |
| Proto shell | PETG FDM (`hardware/cad/case.scad`) | Magnet pocket 0.3 mm loose, then shim |
| Production shell | 6061-T6 CNC | **Not steel** |
| LiPo pouch | 3.7 V **500 mAh**, 5.0 × 30 × 40 mm class | Plugs into BT1 (JST-PH). CAD leftover ~6000 mm³; 500 mAh is the current pick with margin. Buy a **protected** 1S pack |
| Adhesive | 3M VHB or ring stock tape | Phone-facing per vendor |
| Screws | M1.6 | Four bosses; or snap-fit on plastic |

## Phase 0 (no custom PCB)

| Item | Part |
| --- | --- |
| Dev board | ESP32-S3-Korvo-2 (preferred) or ESP-BOX |
| Storage | microSD on Korvo |
| Battery | 3.7 V LiPo on the board battery socket |
| Cable | USB for serial; MSC after the core is stable |

## Battery life (CAD leftover, codec included)

Current pouch is **500 mAh** after the first height-stack / pocket check (`hardware/cad/check_envelope.py`). Change it if leftover volume or measured current changes. MCU-only 126 mA was optimistic.

Record (MCU + ES8311 + mic + SD, **PA off**): ~160 mA from the cell → **~3.1 h**.

Playback (PA on): higher; measure on Korvo and the first SMT board. Idle deep-sleep is dominated by U3 + always-on LDOs — U5 must actually cut the 3.3 V rail.

| Pouch | Record time (codec, PA off) |
| --- | --- |
| 500 mAh (current) | ~3.1 h |
| 600 mAh (pocket max est.) | ~3.8 h |

Re-measure record current on the custom board and update this table before a metal shell.

## Software (computer, not on device)

| Item | Notes |
| --- | --- |
| whisper.cpp | `software/transcribe.py` wraps it on dumped 48 kHz WAVs |

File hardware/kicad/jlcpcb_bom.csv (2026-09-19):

Comment | Designator | Footprint | LCSC Part #
JST-PH 1S | BT1 | JST_PH_S2B-PH-K_1x02_P2.00mm_Horizontal | C173752
22uF | C1 | C_0805_2012Metric | C45783
1uF | C2,C6,C9,C10,C11,C12,C13,C15,C16,C17,C18,C19 | C_0603_1608Metric | C15849
100nF | C3,C14 | C_0603_1608Metric | C14663
4.7uF | C4,C5 | C_0603_1608Metric | C19666
2.2uF | C7 | C_0603_1608Metric | C23630
10uF | C8,C20 | C_0805_2012Metric | C15850
10uF | C21 | C_0603_1608Metric | C96446
status | D1 | LED_0603_1608Metric | C2286
chg | D2 | LED_0603_1608Metric | C2286
500mA PTC | F1 | Fuse_0603_1608Metric | C883095
USB_C_16P | J2 | USB_C_Receptacle_HRO_TYPE-C-31-M-12 | C165948
microSD | J3 | microSD_HC_Wuerth_693072010801 | C91145
IM73A135 | MK1 | IM73A135_PG-LLGA-5-3 | C3171831
10k | R1,R7,R10,Rboot,Rsd0,Rsd1,Rsd2,Rsd3,Rsd4,Rstat | R_0603_1608Metric | C25804
5.11k | R2,R3 | R_0603_1608Metric | C23186
1.8k | R4 | R_0603_1608Metric | C4177
4.7k | R5,R6 | R_0603_1608Metric | C23162
3.01k | R8,R11 | R_0603_1608Metric | C22991
49.9k | R9 | R_0603_1608Metric | C23184
0R | Ragnd | R_0603_1608Metric | C21189
1k | Rchg,Rled | R_0603_1608Metric | C21190
KLJ-01304T-08R07W | SP1 | Speaker_KLJ-01304T | C18186315
record | SW1 | SW_SPST_EVQP7C | C388883
boot | SW_BOOT | SW_Push_1P1T_XKB_TS-1187A | C318885
reset | SW_RST | SW_Push_1P1T_XKB_TS-1187A | C318885
ESP32-S3-MINI-1U-N8 | U1 | ESP32-S3-MINI-1U | C2980299
ES8311 | U2 | QFN-20-1EP_3x3mm_P0.4mm_EP1.65x1.65mm | C962342
BQ24074RGTR | U3 | VQFN-16-1EP_3x3mm_P0.5mm_EP1.6x1.6mm | C54313
AP2112K-3.3 | U4 | SOT-23-5 | C51118
AP22804AW5 | U5 | SOT-23-5 | C3001659
NS4150B | U6 | MSOP-8_3x3mm_P0.65mm | C189961
USBLC6-2SC6 | U7 | SOT-23-6 | C7519
LP5907MFX-2.8 | U8 | SOT-23-5 | C186700
12.288MHz | Y1 | Oscillator_SMD_Abracon_ASE-4Pin_3.2x2.5mm | C49207908

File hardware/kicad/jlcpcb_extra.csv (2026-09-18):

Comment | Designator | Footprint | LCSC Part #
UART0 | J1 | PinHeader_1x04_P2.54mm_Vertical | C124378

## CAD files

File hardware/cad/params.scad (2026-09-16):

// Locked mechanical numbers. Keep in sync with params.json (check_envelope.py compares both).
// Origin: magnet-ring center, phone-facing. +Y toward camera bar, +Z away from glass.

phone_w = 72.0;
phone_h = 152.8;
phone_t = 8.6;
camera_bar_from_top = 24.0;
camera_bar_h = 24.0;
camera_bar_w = 72.0;
camera_bar_extra_t = 3.4;
magnet_cy_from_top = 85.0;
magnet_cx_from_left = 36.0;

magnet_od = 56.0;
magnet_id = 44.0;
magnet_t = 1.1;
shunt_t = 0.3;
adhesive_t = 0.15;

acc_w = 67.0;
acc_h = 90.0;
acc_t = 9.0;
wall = 1.2;
shell_back = 1.2;

pcb_t = 0.8;
pcb_w = 64.0;
pcb_h = 86.0;

usb_offset_x = 8.0;
usb_overmold_len = 18.0;
usb_overmold_w = 12.0;
usb_h = 3.2;

mic_y = 10.0;
btn_y = 12.0;
led_y = 18.0;

batt_t = 5.0;
batt_w = 40.0;
batt_h = 30.0;
batt_off_x = 0.0;
batt_off_y = 10.0;
batt_xy_clear = 0.6;

hole_d = 1.7;
hole_inset = 3.5;

speaker_x = 0.0;
speaker_y = 36.0;
speaker_od = 13.0;
speaker_h = 4.0;

jst_x = -23.5;
jst_y = 34.0;
jst_h = 6.0;

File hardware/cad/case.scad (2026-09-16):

// Printable two-piece PETG chassis (tray toward phone, lid toward pocket).
// Magnet pocket is 0.3 mm loose for the first print. Shim, then tighten after the real ring arrives.
// Later CNC copy: 6061, not steel. Isolate the shunt from aluminium with tape.
//
// World XY origin is the magnet center. +Z is away from the phone glass.
// All cutouts use that map. Do not wrap lid features in an extra +tray_h.

include <params.scad>;

$fn = 64;

// Derived split: tray is phone face through the PCB. Lid is everything above.
pcb_z = adhesive_t + magnet_t + shunt_t;
parts_z = pcb_z + pcb_t;
tray_h = parts_z;
lid_h = acc_t - tray_h;

// Print-fit only. Not locked in params.json.
pocket_extra = 0.3;
magnet_floor = 0.4;
pcb_clear = 0.3;
corner_r = 2.5;
// Lip outer sits on the rim outside the PCB rebate (0.45 mm/side at these numbers).
lip_inset = 0.75;
lip_w = 1.0;
lip_h = 1.2;
lip_clear = 0.2;
usb_slot_w = usb_overmold_w + 1.0;
usb_slot_h = usb_h + 1.0;
eps = 0.05;
// MK1 NPTH from recorder.kicad_pcb: footprint (30, 10) rot 90°, pad
// local (0.68, 0). KiCad PCB rotation is clockwise → board (30.00, 9.32).
// Duct to that hole, not the footprint centre. MK1 stays on F.Cu.
mic_npth_x = 30.00;
mic_npth_y = 9.32;
duct_well = 3.0;
duct_w = 3.0;
duct_floor = 0.5;

module rounded_box(w, h, t, r) {
    r2 = max(0.01, min(r, w / 2 - 0.01, h / 2 - 0.01));
    hull() {
        for (sx = [-1, 1], sy = [-1, 1])
            translate([sx * (w / 2 - r2), sy * (h / 2 - r2), 0])
                cylinder(h = t, r = r2);
    }
}

module acc_body(h) {
    rounded_box(acc_w, acc_h, h, corner_r);
}

module rounded_ring(ow, oh, iw, ih, t, r) {
    difference() {
        rounded_box(ow, oh, t, r);
        translate([0, 0, -eps])
            rounded_box(iw, ih, t + 2 * eps, max(0.2, r - (ow - iw) / 2));
    }
}

// Annular well from a printable floor up to the PCB. Center stays open.
// The ring sits on the floor and cannot fall through the phone face.
module magnet_pocket() {
    translate([0, 0, magnet_floor])
        cylinder(h = pcb_z - magnet_floor + 0.05, d = magnet_od + pocket_extra);
}

module shunt_pocket() {
    translate([0, 0, adhesive_t + magnet_t])
        cylinder(h = shunt_t + 0.15, d = magnet_od + 1.4);
}

module magnet_id_bore() {
    translate([0, 0, -eps])
        cylinder(h = tray_h + 2 * eps, d = magnet_id - 0.8);
}

// 0.3 mm/side. Uses the 0.6 mm leftover outside 2×1.2 mm walls. 0.2 mm was too tight for FDM.
module pcb_rebate() {
    translate([-pcb_w / 2 - pcb_clear, -pcb_h / 2 - pcb_clear, pcb_z])
        cube([pcb_w + 2 * pcb_clear, pcb_h + 2 * pcb_clear, pcb_t + 0.05]);
}

module boss_solid(x, y) {
    translate([x, y, 0])
        cylinder(h = tray_h, d = 4.0);
}

module boss_solids() {
    ix = pcb_w / 2 - hole_inset;
    iy = pcb_h / 2 - hole_inset;
    boss_solid(ix, iy);
    boss_solid(-ix, iy);
    boss_solid(ix, -iy);
    boss_solid(-ix, -iy);
}

module tray_screws() {
    // hole_d 1.7 is M1.6 clearance, not a tap.
    ix = pcb_w / 2 - hole_inset;
    iy = pcb_h / 2 - hole_inset;
    for (p = [[ix, iy], [-ix, iy], [ix, -iy], [-ix, -iy]])
        translate([p[0], p[1], -eps])
            cylinder(h = tray_h + 2 * eps, d = hole_d);
}

module lid_screws() {
    ix = pcb_w / 2 - hole_inset;
    iy = pcb_h / 2 - hole_inset;
    for (p = [[ix, iy], [-ix, iy], [ix, -iy], [-ix, -iy]])
        translate([p[0], p[1], tray_h - eps])
            cylinder(h = lid_h + 2 * eps, d = hole_d + 0.2);
}

// Rectangular first-pass mouth. Connector-accurate J2 pocket waits for real placement.
// Starts at PCB copper so the tray gets a real bite, not a 0.6 mm sliver.
module usb_slot() {
    translate([
        usb_offset_x - usb_slot_w / 2,
        -acc_h / 2 - 1.0,
        pcb_z
    ])
        cube([usb_slot_w, wall + 6.0, usb_slot_h]);
}

// Side features live at PCB top. Nudge 0.3 mm into the tray so the split still cuts.
module mic_port() {
    translate([acc_w / 2 - wall - 1.0, mic_y - 1.5, parts_z - 0.3])
        cube([wall + 2.5, 3.0, 2.0]);
}

// Under-PCB air path: B.Cu NPTH → well → +X channel → right wall → mic_port().
// Phone-face floor stays (z = 0 .. duct_floor). Does not enter the magnet well.
module mic_duct() {
    air_h = pcb_z - duct_floor + eps;
    union() {
        translate([mic_npth_x - duct_well / 2, mic_npth_y - duct_well / 2, duct_floor])
            cube([duct_well, duct_well, air_h]);
        translate([mic_npth_x, mic_npth_y - duct_w / 2, duct_floor])
            cube([acc_w / 2 - mic_npth_x + 1.0, duct_w, air_h]);
        translate([acc_w / 2 - wall - 1.0, mic_y - 1.5, duct_floor])
            cube([wall + 2.5, 3.0, tray_h - duct_floor + eps]);
    }
}

// SW1 is a side-actuated EVQP7C01P aimed at this wall, so the aperture is a
// straight press-through path and not somewhere to hide a lever. It used to
// be 7.0 x 3.5 mm, sized for "whatever mechanism this ends up needing" back
// when the switch was a top plunger. The actuator is 1.7 mm wide and the body
// stands 1.35 mm off the board, so 3.0 x 2.2 mm covers it with margin for
// print tolerance and keeps the opening small enough to take a moulded nub.
// The nub has to span 0.9 mm from the inner wall face to the actuator tip.
module button_hole() {
    translate([-acc_w / 2 - 1.0, btn_y - 1.5, parts_z - 0.3])
        cube([wall + 2.5, 3.0, 2.2]);
}

module led_window() {
    translate([-acc_w / 2 - 0.5, led_y - 0.8, parts_z + 0.4])
        cube([wall + 1.5, 1.6, 1.6]);
}

module tray_lip() {
    translate([0, 0, tray_h - 0.3])
        rounded_ring(
            acc_w - 2 * lip_inset,
            acc_h - 2 * lip_inset,
            acc_w - 2 * lip_inset - 2 * lip_w,
            acc_h - 2 * lip_inset - 2 * lip_w,
            lip_h + 0.3,
            max(0.4, corner_r - lip_inset)
        );
}

module lid_groove() {
    translate([0, 0, tray_h])
        rounded_ring(
            acc_w - 2 * lip_inset + 2 * lip_clear,
            acc_h - 2 * lip_inset + 2 * lip_clear,
            acc_w - 2 * lip_inset - 2 * lip_w - 2 * lip_clear,
            acc_h - 2 * lip_inset - 2 * lip_w - 2 * lip_clear,
            lip_h + 0.2,
            max(0.3, corner_r - lip_inset + lip_clear)
        );
}

module lid_inner() {
    land = lip_inset + lip_w + lip_clear + 0.6;
    translate([0, 0, tray_h - eps])
        rounded_box(
            acc_w - 2 * land,
            acc_h - 2 * land,
            lip_h + 2 * eps,
            max(0.4, corner_r - land)
        );
    translate([0, 0, tray_h + lip_h - eps])
        rounded_box(
            acc_w - 2 * wall,
            acc_h - 2 * wall,
            lid_h - lip_h - shell_back - 0.2,
            max(0.4, corner_r - wall)
        );
}

// 40×30×5 leftover pocket at (0, 10): +Y of U1 (+14, −18) and J2, −Y of SP1 (0, 36).
// Closed 1.2 mm back: the fence hangs from the inner face of shell_back.
// Wall thickness is `wall` (1.2 mm). At batt_off_y=12 the +Y face sat 0.7 mm
// from the 13 mm can and overlapped it in Z; 10 mm is the printable seat.
module battery_fence() {
    outer_w = batt_w + 2 * batt_xy_clear + 2 * wall;
    outer_h = batt_h + 2 * batt_xy_clear + 2 * wall;
    inner_w = batt_w + 2 * batt_xy_clear;
    inner_h = batt_h + 2 * batt_xy_clear;
    fence_h = 3.5;
    embed = 0.8;
    translate([batt_off_x, batt_off_y, 0]) {
        translate([-outer_w / 2, -outer_h / 2, acc_t - shell_back])
            cube([outer_w, outer_h, embed]);
        translate([-outer_w / 2, -outer_h / 2, acc_t - shell_back - fence_h])
            difference() {
                cube([outer_w, outer_h, fence_h + 0.2]);
                translate([(outer_w - inner_w) / 2, (outer_h - inner_h) / 2, -eps])
                    cube([inner_w, inner_h, fence_h + 0.3]);
            }
    }
}

module tray() {
    difference() {
        union() {
            difference() {
                union() {
                    acc_body(tray_h);
                    tray_lip();
                }
                magnet_pocket();
                shunt_pocket();
                magnet_id_bore();
                pcb_rebate();
                usb_slot();
                mic_port();
                mic_duct();
                button_hole();
            }
            boss_solids();
        }
        tray_screws();
    }
}

// SP1 faces the lid. Seven holes through shell_back, centred on the can.
module speaker_grille() {
    translate([speaker_x, speaker_y, acc_t - shell_back - eps]) {
        cylinder(h = shell_back + 2 * eps, d = 2.2);
        for (a = [0:60:300])
            rotate([0, 0, a])
                translate([3.5, 0, 0])
                    cylinder(h = shell_back + 2 * eps, d = 1.8);
    }
}

// S2B-PH-K is 6.0 mm tall. Lid cavity above the PCB is 5.45 mm, so the
// housing peeks into shell_back. Origin is BT1 pad 1; body is the KiCad
// fab box at 0° (cable toward y=+43).
module jst_window() {
    translate([
        jst_x - 2.35,
        jst_y - 1.75,
        acc_t - shell_back - eps
    ])
        cube([6.7, 8.4, shell_back + 2 * eps]);
}
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

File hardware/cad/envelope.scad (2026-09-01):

// Pixel 10 + Pixelsnap accessory envelope (visualization / keepouts).
// Printable chassis is case.scad. Numbers: params.scad.

include <params.scad>;

$fn = 80;

module phone_body() {
    translate([-magnet_cx_from_left, magnet_cy_from_top - phone_h, -phone_t])
        cube([phone_w, phone_h, phone_t]);
}

module camera_bar() {
    translate([-magnet_cx_from_left,
               magnet_cy_from_top - camera_bar_from_top,
               0])
        cube([camera_bar_w, camera_bar_from_top, camera_bar_extra_t]);
}

module magnet_ring() {
    translate([0, 0, adhesive_t])
        difference() {
            cylinder(h = magnet_t, d = magnet_od);
            translate([0, 0, -0.1])
                cylinder(h = magnet_t + 0.2, d = magnet_id);
        }
}

module shunt() {
    translate([0, 0, adhesive_t + magnet_t])
        cylinder(h = shunt_t, d = magnet_od + 1.0);
}

module accessory_outline(h = acc_t) {
    translate([-acc_w / 2, -acc_h / 2, 0])
        cube([acc_w, acc_h, h]);
}

module usb_overmold() {
    // Cable leaves the bottom short edge, still in the plane of the phone back.
    translate([usb_offset_x - usb_overmold_w / 2, -acc_h / 2 - usb_overmold_len, 0])
        cube([usb_overmold_w, usb_overmold_len, usb_h]);
}

module mic_port() {
    translate([acc_w / 2 - 0.2, mic_y - 1.5, adhesive_t + magnet_t + shunt_t + pcb_t])
        cube([wall + 0.4, 3.0, 1.5]);
}

module pcb() {
    z = adhesive_t + magnet_t + shunt_t;
    translate([-pcb_w / 2, -pcb_h / 2, z])
        cube([pcb_w, pcb_h, pcb_t]);
}

%phone_body();
#camera_bar();
color("SteelBlue") magnet_ring();
color("Silver") shunt();
color("ForestGreen", 0.4) pcb();
color("Orange", 0.3) accessory_outline();
color("Red", 0.5) usb_overmold();
color("Yellow") mic_port();

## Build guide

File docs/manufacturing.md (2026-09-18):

# Manufacturing

One-off / quick-turn. Prefer JLCPCB + LCSC Basic parts. Do not send Gerbers until ERC, DRC, envelope check, and `recorder_test` pass.

## PCB (Phase 1)

| Item | Default |
| --- | --- |
| Fab | JLCPCB (PCBWay is the backup) |
| Layers | 4 (F.Cu, In1.Cu, In2.Cu, B.Cu) |
| Thickness | 0.8 mm (`params.json`). 1.6 mm only if a later envelope check still passes |
| Finish | ENIG (USB-C and fine pitch) |
| Impedance | None. Do not order the controlled-impedance option. USB is full speed only, so D+/D− are a plain 0.2 mm pair on a 0.4 mm pitch over In1 GND (~75 Ω). Reasoning in `hardware/kicad/README.md` |
| Min trace / space | 0.15 mm. Inside standard capability, so no fine-line surcharge |
| Via | 0.6 mm pad on a 0.3 mm drill, one size everywhere. 0.3 mm is JLC's preferred hole, so no small-via surcharge — do not let a re-route drop below it |
| Silkscreen | Standard font, 1.0 mm characters on a 0.15 mm stroke. Not the high-precision option |
| Assembly | JLCPCB SMT for every surface-mount part, wave solder for BT1, extra-parts bag for J1 (do not assemble the UART header) |
| Panel | Single board is fine for a one-off |

Mic: keep the acoustic port on the board edge, away from U4/U5 and the USB connector. SD: low-profile push-push or friction socket; if height blows the envelope, redesign for eMMC (still a solved pattern).

See [`hardware/kicad/README.md`](../hardware/kicad/README.md) for stackup and keepouts.

## Magnet array

Buy a **commodity MagSafe / Qi2 accessory magnet ring** plus matching thin steel shunt. Do not CNC magnets. Pocket the ring in CAD to the datasheet of the part in the BOM (OD/ID/thickness vary by 1–2 mm across vendors). Adhesive: 3M VHB or the ring’s stock tape, phone-facing side as the vendor intends.

## Plastic prototype (Phase 1 chassis)

- FDM (PETG) for fit checks, or SLS/MJF nylon if the USB-C pocket needs better accuracy
- JLCPCB 3D print or any local service
- Print the magnet pocket slightly loose, shim with tape, then tighten after the real ring arrives

## Metal chassis (Phase 2)

- **6061 aluminum CNC** (JLCPCB / PCBWay)
- **Not steel, not 400-series stainless** as the main shell — it steals flux from the ring
- 3D-print remains the fit gauge; metal is a copy of a passing plastic shell
- Isolate the shunt from the aluminum with a thin plastic or adhesive layer if the CAD shows a shorted loop around the ring

## Battery

Pouch LiPo sized after CAD. Use a protected cell if it still fits; otherwise a PCM board in the leftover volume. Capacity is leftover mm³, not a marketing number — update [`docs/bom.md`](bom.md) when the pouch is picked.

## Order checklist

1. If you changed schematic sources, run `python hardware/kicad/recorder/generate_recorder.py` then `python hardware/kicad/recorder/verify_schematic.py`. That overwrites sheets only. It does not write `recorder.kicad_pcb`.
2. `python scripts/check_gates.py` (envelope, `recorder_test`, schematic ERC, outline/holes, MCU SKU, pins). Official copper DRC is `kicad-cli pcb drc`. A clean run writes the whole upload package in one pass: `hardware/kicad/fab/` from `kicad-cli`, and `hardware/kicad/jlcpcb_bom.csv` + `jlcpcb_cpl.csv` + `jlcpcb_extra.csv` from `generate_jlc.py`. Send them only if that run just happened. If gates or DRC fail, edit the board. Do not stop at the report.
3. Optional: ngspice `sim/spice/power_path.cir`
4. Human glance in KiCad 10: USB length/impedance, courtyard collisions, 3D vs case. Footprint XY: `hardware/kicad/recorder/placement.json`.
5. Upload `hardware/kicad/fab/` Gerbers + `hardware/kicad/jlcpcb_bom.csv` + `jlcpcb_cpl.csv` to JLCPCB. Step 2 writes those from `recorder.kicad_pcb`, so upload the files that run just produced. Do not hand-edit the CSVs: LCSC order codes come from the tables in [`docs/bom.md`](bom.md), and which parts the machine places comes from the board's own `exclude_from_pos_files` / `exclude_from_bom` flags. A missing LCSC on an assembly-BOM part fails the generator. BT1 is through-hole: it is in the BOM for wave solder, not in the pick-and-place file. J1 is through-hole and **off** the assembly BOM — add `jlcpcb_extra.csv` under Extra Parts in the JLC cart so they ship the header loose; do not wave-solder it. **SP1:** JLC places C18186315 from their EasyEDA library 0° (`BUZ-SMD_4P-L13.0-W13.0-P11.4-BL`, pin 1 bottom-left), not this KiCad land's 0° (pad 1 bottom-right). CPL rotation is 0. In the assembly preview, the coil must sit on the numbered pads toward the analog island, not on the dummy pair toward the top edge. A left-right swap only inverts polarity. 180° leaves the speaker open.
6. Order magnet ring and LiPo **before** locking CNC metal
7. SMT board: follow [`docs/bringup-custom.md`](bringup-custom.md)

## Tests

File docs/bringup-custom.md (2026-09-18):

# Custom-board bring-up

Do this on the first SMT board **after** `python scripts/check_gates.py` is green. Do not power a board that failed ERC/DRC/envelope/`recorder_test`.

Gerbers + JLC BOM/CPL: `hardware/kicad/fab/`, `hardware/kicad/jlcpcb_bom.csv`, `jlcpcb_cpl.csv`, and `jlcpcb_extra.csv`. A green `check_gates.py` writes them from `hardware/kicad/recorder/recorder.kicad_pcb`, so order from the files that run just produced. Do not power or order from an export that still fails DRC.

## Flash

USB-C is the first-flash path (ESP32-S3 USB-Serial/JTAG). After TinyUSB MSC takes the USB-C port, use the two top-actuated buttons **with the lid off**:

1. Hold **Boot** (SW_BOOT, GPIO0 to GND).
2. Tap **Reset** (SW_RST, EN to GND), then release Reset.
3. Release Boot.
4. `idf.py -p COMx flash` over USB-C, or UART0 on J1 (3V3, U0RXD, U0TXD, GND) if you hand-soldered the extra-parts header. JLC does not assemble J1.

The 5 mm actuators sit 1.65 mm under the outer skin. A hole in 1.2 mm PETG does not reach them. Do not wire GPIO0 as a firmware button. SW1 stays the record control.

## Order of tests

1. **USB serial** — native USB-Serial/JTAG or UART0. Confirm the S3 enumerates and `idf.py monitor` shows `pixel-snap-voice on custom`.
2. **Rails** — **VDD33** at U4/U5 (MCU, 3.3 V) vs **3V3A** at U8 LP5907-2.8 (~2.8 V). They must not be shorted together. **3V3A is 2.8 V on purpose**: IM73A135 VDD abs max is 3.0 V. **VSYS** at U3 OUT / U4 VIN (USB ~4.4 V or cell). **VBAT** ~3.7–4.2 V at BT1 with a pouch; it must not be strapped to VSYS. VBUS ~5 V when plugged in (J2).
3. **I2C codec** — scan address 0x18. ES8311 ACK.
4. **I2S** — codec is master. Y1 is the 12.288 MHz oscillator into ES8311 MCLK. Scope MCLK/BCLK/WS. Play a tone / loopback before trusting the mic.
5. **Mic capture** — short press records `/recordings/YYYYMMDD-HHMMSS.wav` at 48 kHz. Copy off via SD reader if MSC is not up yet. Play on a desktop.
6. **SD** — 4-bit SDMMC. `storage_sd_mount` log line.
7. **Playback** — double-press plays last file through NS4150 / SP1 (KELIKING KLJ-01304T). Check the lid grille is over the can. NS4150B runs from **VSYS**; at ~4.4 V on USB or 4.2 V on a full pouch into 8 Ω the PA can sit on the speaker's 1 W max. Firmware still advertises `pa_voltage = 5.0`, which keeps digital gain down. Confirm polarity (a left-right JLC mismatch only inverts phase; a 180° mismatch is silent) and that playback volume is comfortable, not a copper change.
8. **Charger** — USB-C 5 V into BQ24074 IN. STAT / **CHG_STAT** low while charging, ~500 mA. Board runs from VSYS with BT1 open. No brownout while recording or playing.
9. **TinyUSB MSC** — plug into a PC; recording stops; volume mounts; unplug returns to idle. Drop `set_time.txt` to set the RTC.
10. **Sleep** — long press; current should drop (U5 off). Wake on the record button.

Measure record current (PA off) and playback current. Update [`docs/bom.md`](bom.md) hours from `mAh / measured_mA`. Current pouch is **500 mAh** (~3.1 h at 160 mA) from leftover CAD volume. If measured current is worse, update the BOM and the pouch pick before a metal shell is cut.

## Time

`set_time.txt` at the volume root, one line `YYYY-MM-DD HH:MM:SS` (UTC). Applied on boot and after unmount.

## If something is dead

| Symptom | First check |
| --- | --- |
| No 3.3 V | U4, U5, solder on the module |
| Codec NACK | 3V3A at U8 (~2.8 V), I2C pull-ups, Y1 output on MCLK |
| Hiss / no mic | Analog island, mic port not against glass, MK1 bias at 2.8 V, OUT− not shorted to AGND |
| No MSC | TinyUSB config, SD still mounted by VFS, USB D+/D− swap |
| Brownout on play | USB cable, PA supply from VSYS, decoupling |

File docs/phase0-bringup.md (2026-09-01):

# Phase 0 — DevKit bring-up (before a custom PCB)

Prove **capture, playback, WAV headers, and storage** on off-the-shelf hardware. You can still design the custom board in parallel. Do not send Gerbers until this path has recorded a playable 48 kHz WAV, unless you accept spinning the board.

MCU stays ESP32-S3. The missing pieces on a Sense-only board are the **codec and amp**. Prefer a voice-oriented Espressif board for Phase 0.

## Preferred board

**ESP32-S3-Korvo-2** or **ESP-BOX** (ES8311 + analog mic + class-D PA). This is the same audio path as the custom PCB.

Close second: [ESP32-OpenMic](https://codeberg.org/RevK/ESP32-OpenMic) (S3 module + ICS-43434 + MAX98357A + microSD + USB MSC). Faster MSC, slightly worse capture SNR.

**Seeed XIAO ESP32-S3 Sense** is only for the portable recorder core (buttons, WAV writer, SD). It cannot prove headphone/speaker quality.

## What “done” means

1. Button starts and stops a recording.
2. File appears as `/recordings/YYYYMMDD-HHMMSS.wav`.
3. WAV is **48 kHz**, 16-bit, mono PCM and plays in a desktop player.
4. Device can play that file (or a fixture WAV) through the board speaker or HP jack.
5. USB-C: pull the SD card at first; TinyUSB MSC comes after the core is stable.
6. Battery: runs from LiPo and charges from USB-C without browning out while recording or playing.

On-device transcription, Wi-Fi, and the magnet shell are **not** Phase 0.

## Toolchain

See [`firmware/README.md`](../firmware/README.md) for board Kconfig, buttons, and `set_time.txt`.

```bash
cd firmware
idf.py set-target esp32s3
idf.py build
idf.py -p COMx flash monitor
```

Use `esp_codec_dev` + the Korvo/ESP-BOX ES8311 example for duplex I2S. Host-side iteration (no hardware):

```bash
cmake -S sim/host -B build/host
cmake --build build/host
./build/host/recorder_test
./build/host/recorder_sim
```

## Korvo-2 / ESP-BOX

Follow Espressif’s user guide for I2C to ES8311, I2S pins, PA enable, and analog mic bias. Set the codec as **I2S master** if the board clock allows; otherwise match the Espressif example and accept S3-generated clocks for Phase 0 only. Custom PCB must use the 12.288 MHz oscillator into ES8311 MCLK in [`audio-platform.md`](audio-platform.md).

## Sense (recorder core only)

| Function | Sense (typical — check current wiki) |
| --- | --- |
| PDM clock / data | Sense mic header |
| microSD | On-board SPI SD |
| Record button | D1 (GPIO1) to GND, pull-up |
| USB / battery | On-board USB-C, BAT± |

Do not enable Wi-Fi.

## USB Mass Storage

Phase 0 can skip MSC and use an SD reader. When the portable core is stable, enable ESP-IDF TinyUSB MSC (OpenMic `sdusb`): recording disabled while mounted.

## Power notes

- USB 5 V and LiPo at once is normal on XIAO / Korvo.
- Measure record **and playback** current; codec + PA are extra vs the MCU-only estimate in architecture.
- If the board resets when the mic + SD + PA start, fix the cable/hub first, then decoupling on the custom PCB.

## What Phase 0 does not prove

- Magnet alignment on a Pixel 10
- Camera-bar clearance
- USB-C plug vs phone body while snapped on
- Analog LDO / ES8311 master clock as laid out on the custom PCB
- 6061 chassis

After a playable WAV exists **and** on-board playback works, move to CAD fit and KiCad — still no fab order.

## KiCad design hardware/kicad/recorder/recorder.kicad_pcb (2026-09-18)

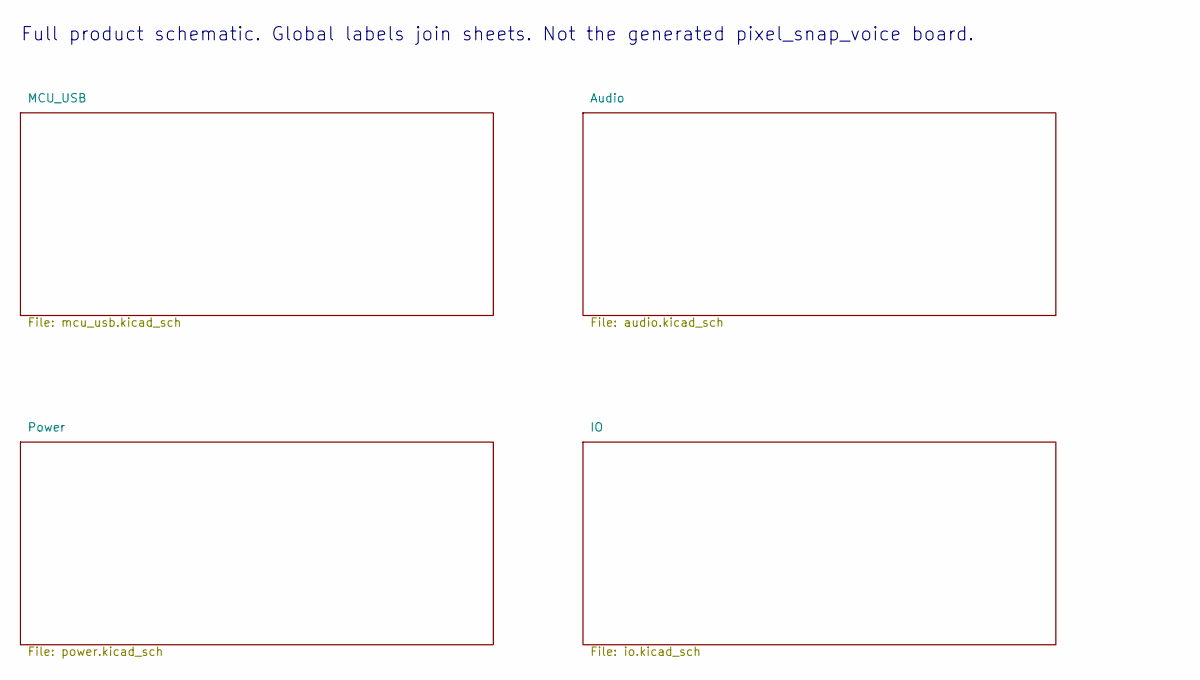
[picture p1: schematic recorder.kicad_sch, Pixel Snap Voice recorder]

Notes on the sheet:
Full product schematic. Global labels join sheets. Not the generated pixel_snap_voice board.

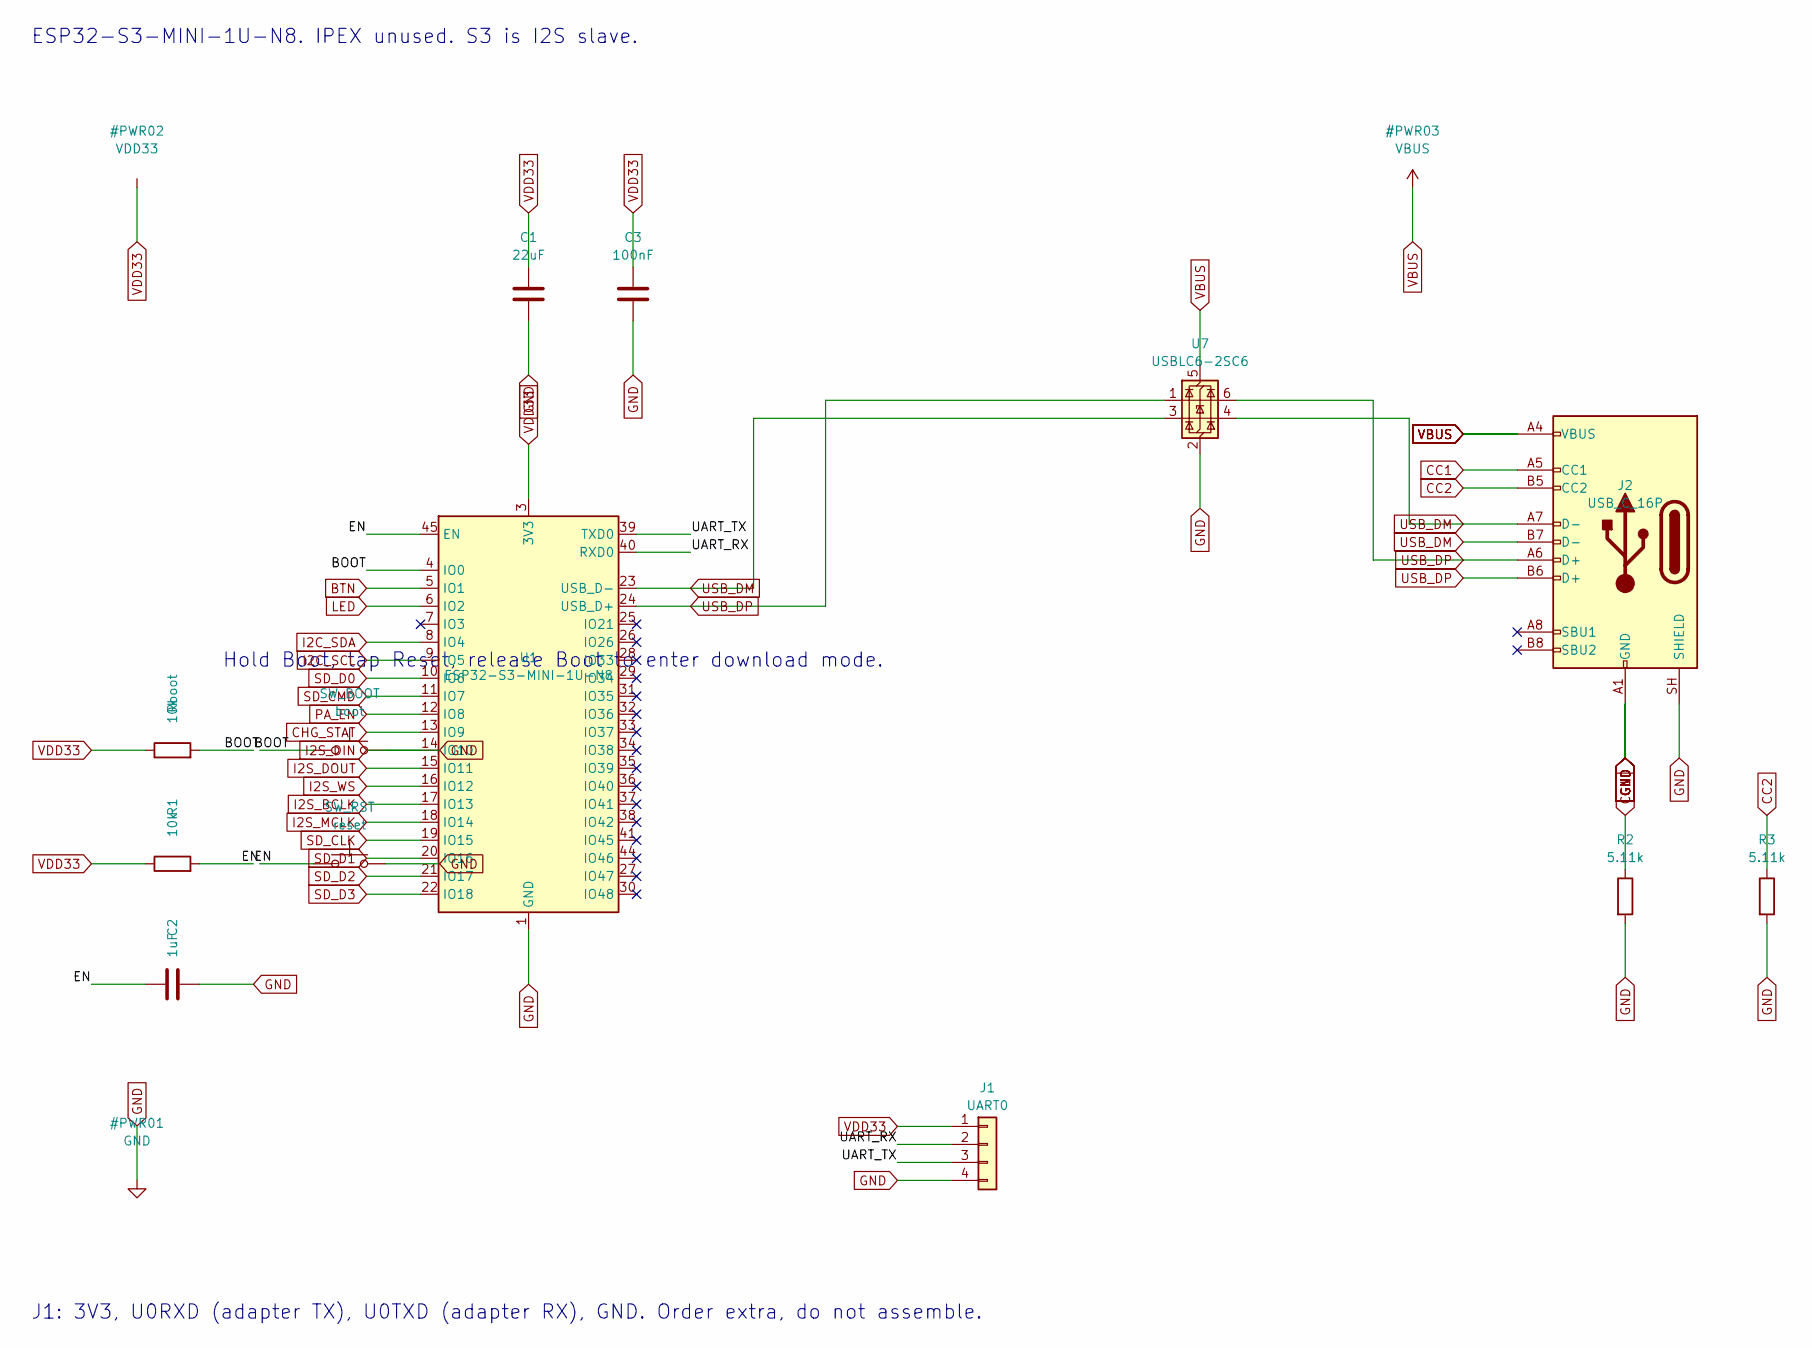
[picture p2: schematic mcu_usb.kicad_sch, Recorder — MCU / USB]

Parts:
C1: 22uF; C_0805_2012Metric
C2: 1uF; C_0603_1608Metric
C3: 100nF; C_0603_1608Metric
J1: UART0; PinHeader_1x04_P2.54mm_Vertical
J2: USB_C_16P; USB_C_Receptacle_HRO_TYPE-C-31-M-12
R1: 10k; R_0603_1608Metric
R2, R3: 5.11k; R_0603_1608Metric
Rboot: 10k; R_0603_1608Metric
SW_BOOT: boot; SW_Push_1P1T_XKB_TS-1187A
SW_RST: reset; SW_Push_1P1T_XKB_TS-1187A
U1: ESP32-S3-MINI-1U-N8; ESP32-S3-MINI-1U
U7: USBLC6-2SC6; SOT-23-6

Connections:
/MCU_USB/BOOT: Rboot.2, SW_BOOT.1, U1.4 (IO0)
/MCU_USB/EN: C2.1, R1.2, SW_RST.1, U1.45 (EN)
/MCU_USB/UART_RX: J1.2, U1.40 (RXD0)
/MCU_USB/UART_TX: J1.3, U1.39 (TXD0)
BTN: U1.5 (IO1); also elsewhere on the board
CC1: J2.A5 (CC1), R2.1
CC2: J2.B5 (CC2), R3.1
CHG_STAT: U1.13 (IO9); also elsewhere on the board
GND: C1.2, C2.2, C3.2, J1.4, J2.A1 (GND), J2.A12 (GND), J2.B1 (GND), J2.B12 (GND), J2.SH (SHIELD), R2.2, R3.2, SW_BOOT.2, SW_RST.2, U1.1 (GND), U1.2 (GND), U1.42 (GND), U1.43 (GND), U1.46 (GND), U1.47 (GND), U1.48 (GND), U1.49 (GND), U1.50 (GND), U1.51 (GND), U1.52 (GND), U1.53 (GND), U1.54 (GND), U1.55 (GND), U1.56 (GND), U1.57 (GND), U1.58 (GND), U1.59 (GND), U1.60 (GND), U1.61 (GND), U1.62 (GND), U1.63 (GND), U1.64 (GND), U1.65 (GND), U7.2 (GND); also elsewhere on the board
I2C_SCL: U1.9 (IO5); also elsewhere on the board
I2C_SDA: U1.8 (IO4); also elsewhere on the board
I2S_BCLK: U1.17 (IO13); also elsewhere on the board
I2S_DIN: U1.14 (IO10); also elsewhere on the board
I2S_DOUT: U1.15 (IO11); also elsewhere on the board
I2S_MCLK: U1.18 (IO14); also elsewhere on the board
I2S_WS: U1.16 (IO12); also elsewhere on the board
LED: U1.6 (IO2); also elsewhere on the board
PA_EN: U1.12 (IO8); also elsewhere on the board
SD_CLK: U1.19 (IO15); also elsewhere on the board
SD_CMD: U1.11 (IO7); also elsewhere on the board
SD_D0: U1.10 (IO6); also elsewhere on the board
SD_D1: U1.20 (IO16); also elsewhere on the board
SD_D2: U1.21 (IO17); also elsewhere on the board
SD_D3: U1.22 (IO18); also elsewhere on the board
USB_DM: J2.A7 (D-), J2.B7 (D-), U1.23 (USB_D-), U7.3 (I/O2), U7.4 (I/O2)
USB_DP: J2.A6 (D+), J2.B6 (D+), U1.24 (USB_D+), U7.1 (I/O1), U7.6 (I/O1)
VBUS: J2.A4 (VBUS), J2.A9 (VBUS), J2.B4 (VBUS), J2.B9 (VBUS), U7.5 (VBUS); also elsewhere on the board
VDD33: C1.1, C3.1, J1.1, R1.1, Rboot.1, U1.3 (3V3); also elsewhere on the board

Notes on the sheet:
ESP32-S3-MINI-1U-N8. IPEX unused. S3 is I2S slave.
Hold Boot, tap Reset, release Boot to enter download mode.
J1: 3V3, U0RXD (adapter TX), U0TXD (adapter RX), GND. Order extra, do not assemble.

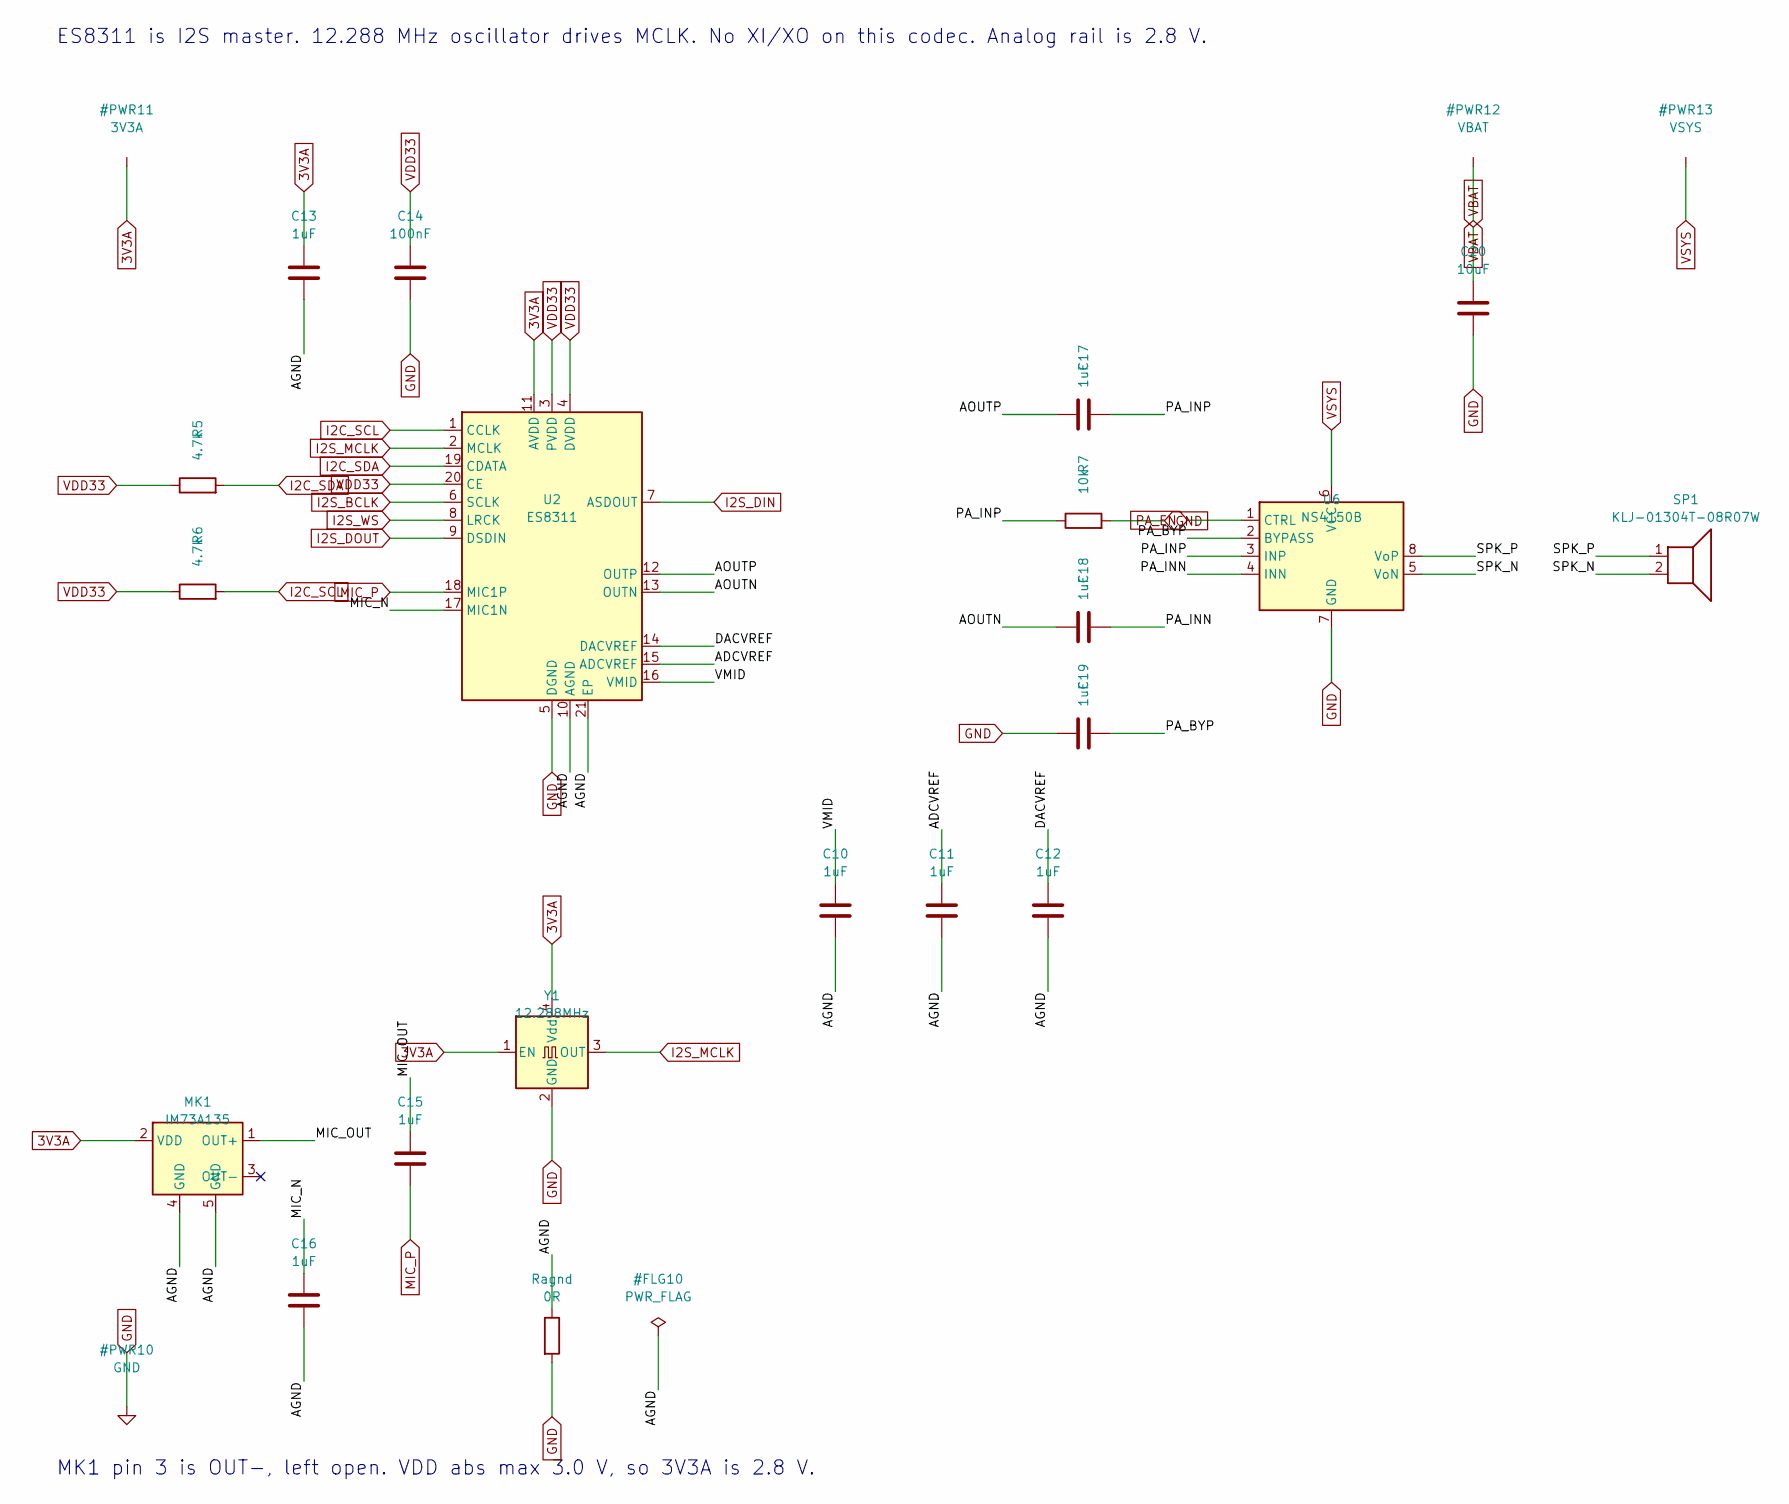
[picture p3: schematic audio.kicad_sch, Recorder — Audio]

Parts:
C10, C11, C12, C13, C15, C16, C17, C18, C19: 1uF; C_0603_1608Metric
C14: 100nF; C_0603_1608Metric
C20: 10uF; C_0805_2012Metric
MK1: IM73A135; IM73A135_PG-LLGA-5-3
R5, R6: 4.7k; R_0603_1608Metric
R7: 10k; R_0603_1608Metric
Ragnd: 0R; R_0603_1608Metric
SP1: KLJ-01304T-08R07W; Speaker_KLJ-01304T
U2: ES8311; QFN-20-1EP_3x3mm_P0.4mm_EP1.65x1.65mm
U6: NS4150B; MSOP-8_3x3mm_P0.65mm
Y1: 12.288MHz; Oscillator_SMD_Abracon_ASE-4Pin_3.2x2.5mm

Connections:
3V3A: C13.1, MK1.2 (VDD), U2.11 (AVDD), Y1.1 (EN), Y1.4 (Vdd); also elsewhere on the board
/Audio/ADCVREF: C11.1, U2.15 (ADCVREF)
/Audio/AGND: C10.2, C11.2, C12.2, C13.2, C16.2, MK1.4 (GND), MK1.5 (GND), Ragnd.1, U2.10 (AGND), U2.21 (EP)
/Audio/AOUTN: C18.1, U2.13 (OUTN)
/Audio/AOUTP: C17.1, U2.12 (OUTP)
/Audio/DACVREF: C12.1, U2.14 (DACVREF)
/Audio/MIC_N: C16.1, U2.17 (MIC1N)
/Audio/MIC_OUT: C15.1, MK1.1 (OUT+)
/Audio/PA_BYP: C19.1, U6.2 (BYPASS)
/Audio/PA_INN: C18.2, U6.4 (INN)
/Audio/PA_INP: C17.2, R7.1, U6.3 (INP)
/Audio/SPK_N: SP1.2, U6.5 (VoN)
/Audio/SPK_P: SP1.1, U6.8 (VoP)
/Audio/VMID: C10.1, U2.16 (VMID)
GND: C14.2, C19.2, C20.2, R7.2, Ragnd.2, U2.5 (DGND), U6.7 (GND), Y1.2 (GND); also elsewhere on the board
I2C_SCL: R6.2, U2.1 (CCLK); also elsewhere on the board
I2C_SDA: R5.2, U2.19 (CDATA); also elsewhere on the board
I2S_BCLK: U2.6 (SCLK); also elsewhere on the board
I2S_DIN: U2.7 (ASDOUT); also elsewhere on the board
I2S_DOUT: U2.9 (DSDIN); also elsewhere on the board
I2S_MCLK: U2.2 (MCLK), Y1.3 (OUT); also elsewhere on the board
I2S_WS: U2.8 (LRCK); also elsewhere on the board
MIC_P: C15.2, U2.18 (MIC1P)
PA_EN: U6.1 (CTRL); also elsewhere on the board
VBAT: C20.1; also elsewhere on the board
VDD33: C14.1, R5.1, R6.1, U2.3 (PVDD), U2.4 (DVDD), U2.20 (CE); also elsewhere on the board
VSYS: U6.6 (VCC); also elsewhere on the board

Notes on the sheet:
ES8311 is I2S master. 12.288 MHz oscillator drives MCLK. No XI/XO on this codec. Analog rail is 2.8 V.
MK1 pin 3 is OUT−, left open. VDD abs max 3.0 V, so 3V3A is 2.8 V.

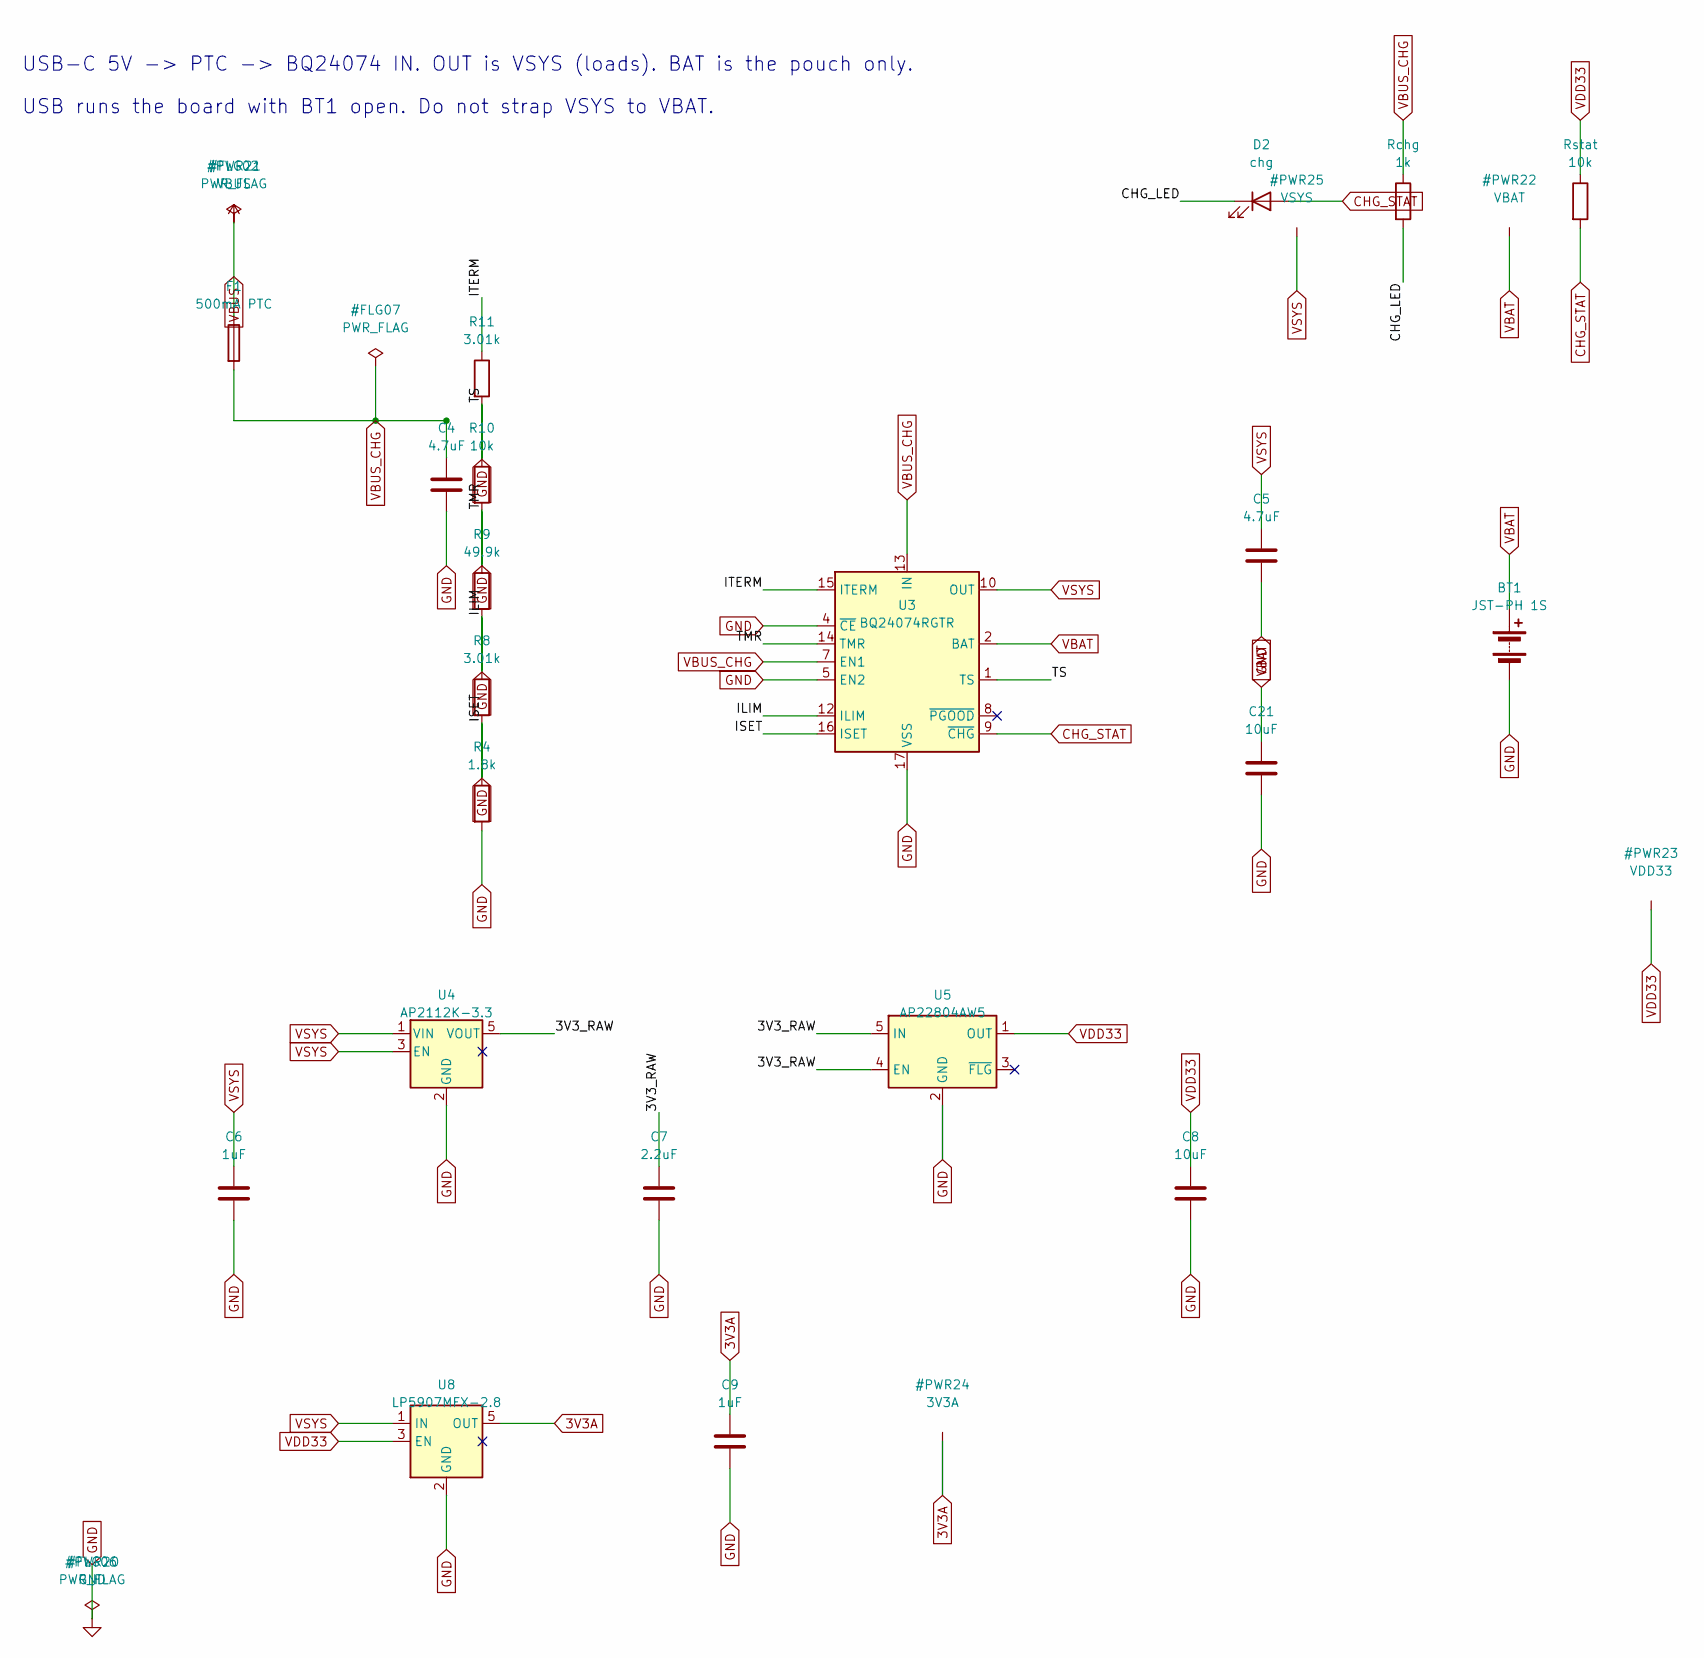
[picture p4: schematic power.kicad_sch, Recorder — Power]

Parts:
BT1: JST-PH 1S; JST_PH_S2B-PH-K_1x02_P2.00mm_Horizontal
C4, C5: 4.7uF; C_0603_1608Metric
C6, C9: 1uF; C_0603_1608Metric
C7: 2.2uF; C_0603_1608Metric
C8: 10uF; C_0805_2012Metric
C21: 10uF; C_0603_1608Metric
D2: chg; LED_0603_1608Metric
F1: 500mA PTC; Fuse_0603_1608Metric
R4: 1.8k; R_0603_1608Metric
R8, R11: 3.01k; R_0603_1608Metric
R9: 49.9k; R_0603_1608Metric
R10: 10k; R_0603_1608Metric
Rchg: 1k; R_0603_1608Metric
Rstat: 10k; R_0603_1608Metric
U3: BQ24074RGTR; VQFN-16-1EP_3x3mm_P0.5mm_EP1.6x1.6mm
U4: AP2112K-3.3; SOT-23-5
U5: AP22804AW5; SOT-23-5
U8: LP5907MFX-2.8; SOT-23-5

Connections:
3V3A: C9.1, U8.5 (OUT); also elsewhere on the board
/Power/3V3_RAW: C7.1, U4.5 (VOUT), U5.4 (EN), U5.5 (IN)
/Power/CHG_LED: D2.1 (K), Rchg.2
/Power/ILIM: R8.1, U3.12 (ILIM)
/Power/ISET: R4.1, U3.16 (ISET)
/Power/ITERM: R11.1, U3.15 (ITERM)
/Power/TMR: R9.1, U3.14 (TMR)
/Power/TS: R10.1, U3.1 (TS)
CHG_STAT: D2.2 (A), Rstat.2, U3.9 (~CHG); also elsewhere on the board
GND: BT1.2 (-), C4.2, C5.2, C6.2, C7.2, C8.2, C9.2, C21.2, R4.2, R8.2, R9.2, R10.2, R11.2, U3.4 (~CE), U3.5 (EN2), U3.17 (VSS), U4.2 (GND), U5.2 (GND), U8.2 (GND); also elsewhere on the board
VBAT: BT1.1 (+), C21.1, U3.2 (BAT), U3.3 (BAT); also elsewhere on the board
VBUS: F1.1; also elsewhere on the board
VBUS_CHG: C4.1, F1.2, Rchg.1, U3.6 (IN), U3.7 (EN1), U3.13 (IN)
VDD33: C8.1, Rstat.1, U5.1 (OUT), U8.3 (EN); also elsewhere on the board
VSYS: C5.1, C6.1, U3.10 (OUT), U3.11 (OUT), U4.1 (VIN), U4.3 (EN), U8.1 (IN); also elsewhere on the board

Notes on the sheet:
USB-C 5V -> PTC -> BQ24074 IN. OUT is VSYS (loads). BAT is the pouch only.
USB runs the board with BT1 open. Do not strap VSYS to VBAT.

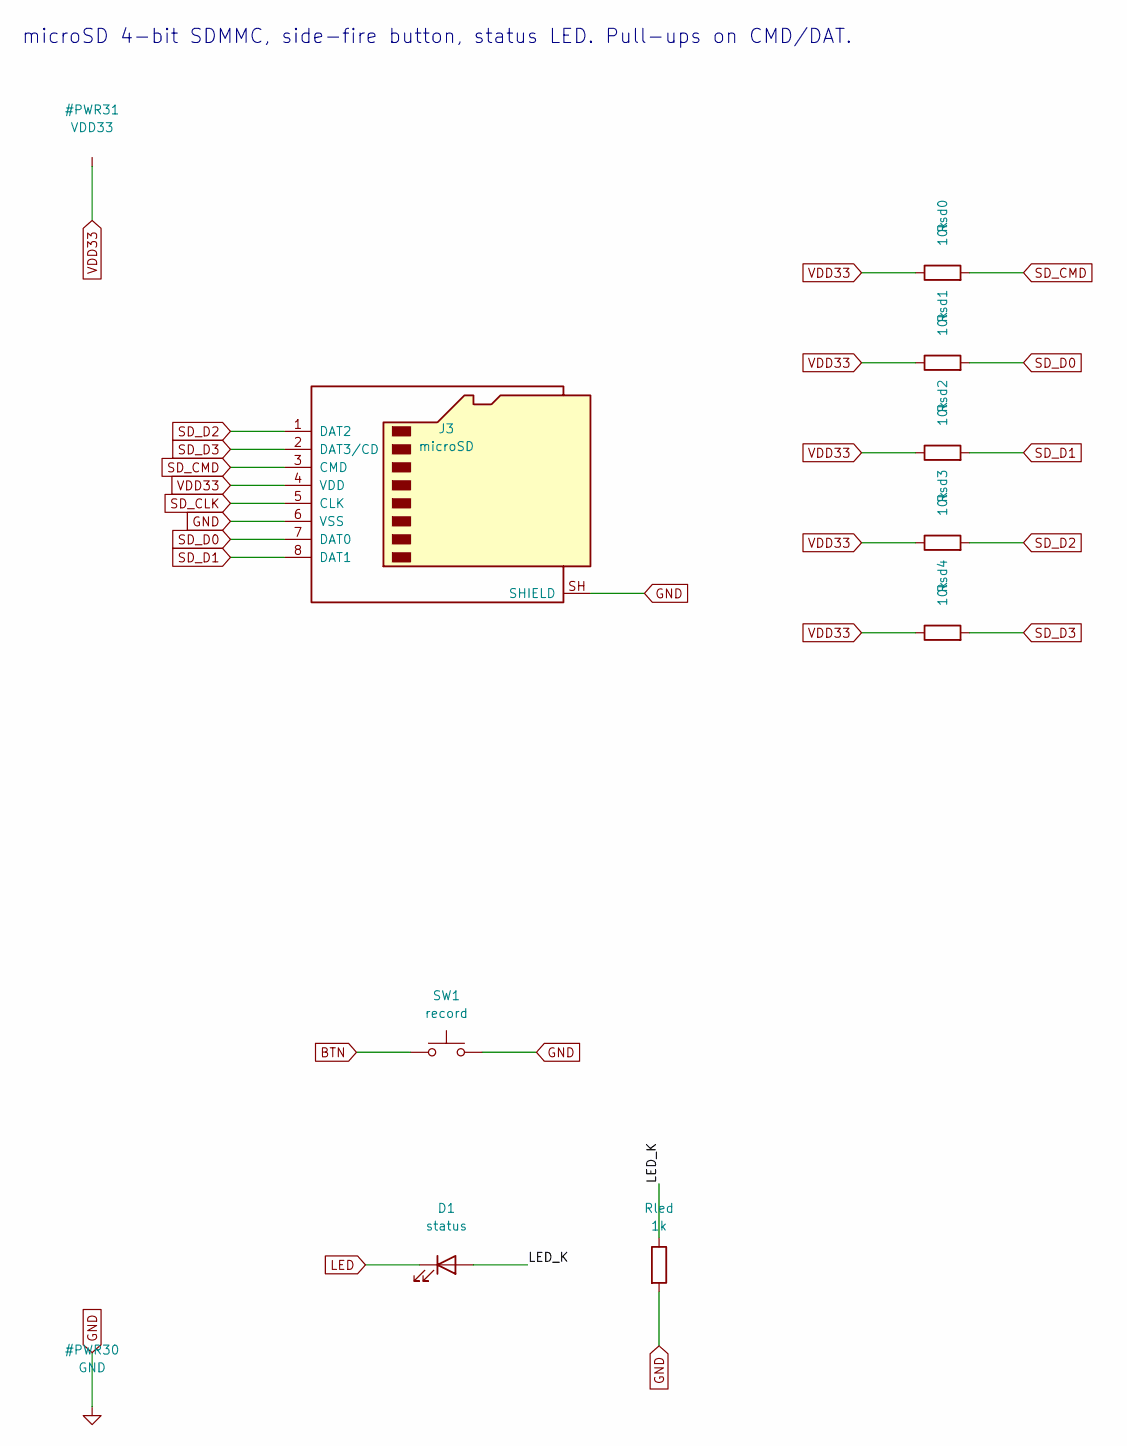
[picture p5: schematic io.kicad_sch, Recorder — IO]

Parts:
D1: status; LED_0603_1608Metric
J3: microSD; microSD_HC_Wuerth_693072010801
Rled: 1k; R_0603_1608Metric
Rsd0, Rsd1, Rsd2, Rsd3, Rsd4: 10k; R_0603_1608Metric
SW1: record; SW_SPST_EVQP7C

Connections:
/IO/LED_K: D1.2 (A), Rled.1
BTN: SW1.1; also elsewhere on the board
GND: J3.6 (VSS), J3.SH (SHIELD), Rled.2, SW1.2; also elsewhere on the board
LED: D1.1 (K); also elsewhere on the board
SD_CLK: J3.5 (CLK); also elsewhere on the board
SD_CMD: J3.3 (CMD), Rsd0.2; also elsewhere on the board
SD_D0: J3.7 (DAT0), Rsd1.2; also elsewhere on the board
SD_D1: J3.8 (DAT1), Rsd2.2; also elsewhere on the board
SD_D2: J3.1 (DAT2), Rsd3.2; also elsewhere on the board
SD_D3: J3.2 (DAT3/CD), Rsd4.2; also elsewhere on the board
VDD33: J3.4 (VDD), Rsd0.1, Rsd1.1, Rsd2.1, Rsd3.1, Rsd4.1; also elsewhere on the board

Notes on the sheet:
microSD 4-bit SDMMC, side-fire button, status LED. Pull-ups on CMD/DAT.

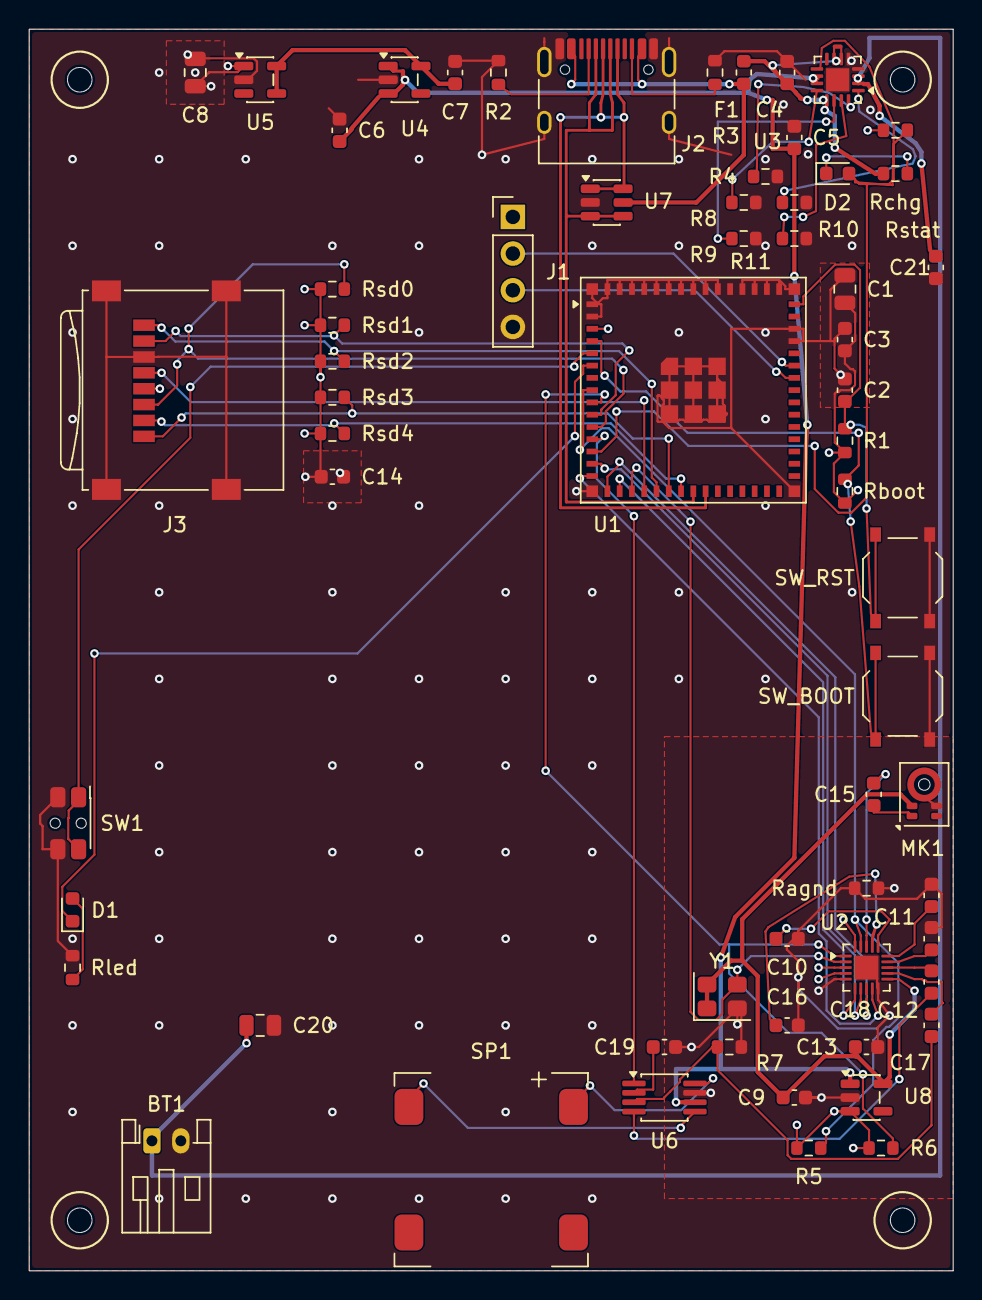
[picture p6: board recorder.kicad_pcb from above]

Board: 4 copper layers, 64.0 x 86.0 mm, 67 parts (0 on the bottom side), 54 nets.

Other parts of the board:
H1, H2, H3, H4: M1.6 NPTH; MountingHole_1.7mm_M1.6

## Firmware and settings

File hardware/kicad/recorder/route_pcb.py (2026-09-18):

#!/usr/bin/env python3
"""Pour planes and route traces on the existing recorder board.

Run with any interpreter that has KiCad 10's ``pcbnew`` module. On Linux the
distro KiCad package puts it in the system python3; on Windows use
``.../KiCad/10.0/bin/python.exe``.

    python3 route_pcb.py                    # planes + full autoroute + pours
    python3 route_pcb.py --planes-only      # re-pour zones, keep the traces
    python3 route_pcb.py --export-dsn F     # planes only, write a Specctra DSN
    python3 route_pcb.py --import-ses F     # apply a session, pour, stitch
    python3 route_pcb.py --finish-only      # drop stub vias, re-seat silk

The router is freerouting (https://freerouting.app), driven headless through
Specctra DSN/SES. The old in-tree A* router that used to live here is gone:
it left 373 DRC errors and 38 open nets, mostly shorts and sub-minimum track
widths, and no amount of grid tuning made it competitive with a real
rip-up-and-retry router. Point PSV_FREEROUTING at the launcher, or put
``freerouting`` on PATH; .cursor/install.sh installs it.

This script loads recorder.kicad_pcb. It never calls CreateEmptyBoard and it
does not move footprints. Edge.Cuts, mounting holes, and placement stay as
they are. It refuses to write while ~recorder.kicad_pcb.lck is present.

Coordinates are the same magnet-centred millimetres as generate_pcb.py.
"""

from __future__ import annotations

import collections
import heapq
import json
import math
import os
import shutil
import subprocess
import sys
import tempfile

import numpy as np
import pcbnew

try:
    import wx
except ImportError:
    wx = None
else:
    # KiCad 10's Windows build still trips PCB_VIA::GetWidth() without a
    # layer inside DSN export. That is a wx assert dialog, not a real DRC
    # failure. Mute it so a headless route can finish.
    wx.DisableAsserts()

from generate_pcb import DESIGN_RULES, apply_project_policy, tuck_reference_text

HERE = os.path.dirname(os.path.abspath(__file__))
REPO = os.path.abspath(os.path.join(HERE, "..", "..", ".."))
PARAMS = os.path.join(REPO, "hardware", "cad", "params.json")
PCB = os.environ.get("PSV_ROUTE_PCB", os.path.join(HERE, "recorder.kicad_pcb"))
PROJECT = os.environ.get("PSV_ROUTE_PRO", os.path.join(HERE, "recorder.kicad_pro"))
PLACEMENT = os.path.join(HERE, "placement.json")
LOCK = os.path.join(HERE, "~recorder.kicad_pcb.lck")
SKIP_LOCK = os.environ.get("PSV_ROUTE_SKIP_LOCK") == "1"

# Analog island on F.Cu: an AGND pour, no F.Cu VDD33 and no F.Cu GND.
# In1.Cu (GND) sits between F.Cu and the In2.Cu VDD33 plane, so the analog
# copper never faces the digital supply even though In2 spans the board.
# 3V3A is routed as traces; it used to be a second pour over the identical
# rectangle at a higher priority, which simply swallowed the AGND pour.
ANALOG = (12.0, 6.0, 32.0, 38.0)

PLANE_NETS = {"GND", "VDD33", "/Audio/AGND"}

# Local F.Cu VDD33 patches around the bulk decoupling only. In2.Cu is the plane.
VDD33_ISLANDS = (
    (22.8, -26.8, 26.2, -16.8, "VDD33_F_C1C3"),
    (-22.5, -42.2, -18.5, -37.8, "VDD33_F_C8"),
    (-13.0, -13.8, -9.0, -10.2, "VDD33_F_C14"),
)

STITCH_OFFSETS = (
    (1.1, 0.0),
    (-1.1, 0.0),
    (0.0, 1.1),
    (0.0, -1.1),
    (0.9, 0.9),
    (-0.9, 0.9),
    (0.9, -0.9),
    (-0.9, -0.9),
    (1.6, 0.0),
    (-1.6, 0.0),
    (0.0, 1.6),
    (0.0, -1.6),
    (1.4, 0.8),
    (-1.4, 0.8),
    (1.4, -0.8),
    (-1.4, -0.8),
    (2.0, 0.0),
    (-2.0, 0.0),
    (0.0, 2.0),
    (0.0, -2.0),
)

CLEARANCE = 0.15
HOLE_CLEARANCE = 0.30
HOLE_TO_HOLE = 0.25
EDGE_CLEAR = 0.35
VIA_SIZE = 0.60
VIA_DRILL = 0.30


def via_width(via):
    """KiCad 10 vias are per-layer; the no-arg GetWidth() asserts."""
    return via.GetFrontWidth()
HOLE_R = 2.1
DEFAULT_WIDTH = 0.15
USB_WIDTH = 0.20
POWER_WIDTH = 0.30
ZONE_CLEARANCE = 0.20

# Same list as NETCLASS_PATTERNS "POWER" in generate_pcb.py: the rails that
# carry charge current rather than logic.
POWER_NETS = {"VBUS", "VBUS_CHG", "VBAT", "VSYS", "/Power/3V3_RAW", "3V3A"}


def vec(x_mm, y_mm):
    return pcbnew.VECTOR2I(pcbnew.FromMM(x_mm), pcbnew.FromMM(y_mm))


def mm(pt):
    return pcbnew.ToMM(pt.x), pcbnew.ToMM(pt.y)


def in_analog(x, y):
    x0, y0, x1, y1 = ANALOG
    return x0 <= x <= x1 and y0 <= y <= y1


def in_charger_keep(x, y):
    """Skip the GND stitch grid over the BQ24074 body.

    H2 sits 3 mm east of U3, so a 6 mm grid via lands on the QFN or crowds
    an ISET pad. The EP gets its own 0.6/0.3 via in fanout_charger.
    """
    return 16.0 <= x <= 27.0 and -42.0 <= y <= -27.0


def ensure_closed():
    if SKIP_LOCK:
        return
    if os.path.isfile(LOCK):
        raise SystemExit(
            "recorder.kicad_pcb is locked. Close the recorder project in "
            "KiCad 10, then run this script again. Writing the board while "
            "it is open would fight the editor."
        )


def net_of(board, name):
    info = board.FindNet(name)
    if info is None or info.GetNetCode() <= 0:
        raise SystemExit(f"board has no net {name!r}")
    return info


def pad_xy(pad):
    return mm(pad.GetPosition())


def pad_wh(pad):
    size = pad.GetSize()
    return pcbnew.ToMM(size.x), pcbnew.ToMM(size.y)


def is_npth(pad):
    return pad.GetAttribute() == pcbnew.PAD_ATTRIB_NPTH


def copper_pads(board):
    out = []
    for fp in board.GetFootprints():
        for pad in fp.Pads():
            if is_npth(pad):
                continue
            name = pad.GetNetname()
            if not name or name.startswith("unconnected-"):
                continue
            out.append((fp, pad, name))
    return out


# ---------------------------------------------------------------------------
# Copper primitives
# ---------------------------------------------------------------------------


def add_rect_zone(board, net, layer, x0, y0, x1, y1, name, priority):
    return add_poly_zone(
        board,
        net,
        layer,
        ((x0, y0), (x1, y0), (x1, y1), (x0, y1)),
        name,
        priority,
    )


def add_poly_zone(board, net, layer, points, name, priority):
    zone = pcbnew.ZONE(board)
    zone.SetLayer(layer)
    if net is not None:
        zone.SetNet(net)
    zone.SetAssignedPriority(priority)
    zone.SetLocalClearance(pcbnew.FromMM(ZONE_CLEARANCE))
    zone.SetMinThickness(pcbnew.FromMM(0.20))
    # Solid pad connections. Thermal spokes tripped starved_thermal on every
    # pad the pour could only reach from one side, and the board is reflowed.
    zone.SetPadConnection(pcbnew.ZONE_CONNECTION_FULL)
    # Drop fill fragments that no pad or via reaches. On a stitched plane the
    # leftovers are slivers between via barrels, and DRC counts each one as an
    # unconnected item.
    zone.SetIslandRemovalMode(pcbnew.ISLAND_REMOVAL_MODE_ALWAYS)
    zone.SetZoneName(name)
    outline = zone.Outline()
    outline.NewOutline()
    for x, y in points:
        outline.Append(pcbnew.FromMM(x), pcbnew.FromMM(y))
    board.Add(zone)
    return zone


# Copper this script placed by hand. KiCad's Specctra export writes locked
# items as "(type fix)", which freerouting honours, so the connector escape
# and the fine-pitch fanout survive the autorouter instead of being ripped up
# and left as orphan stubs. The set is also what keeps the repair loop's
# rip-up from cutting the very fanout it depends on.
PROTECTED = set()


def _seg_key(x0, y0, x1, y1, layer):
    a = (round(x0, 3), round(y0, 3))
    b = (round(x1, 3), round(y1, 3))
    return (layer,) + (a + b if a <= b else b + a)


def relock(board):
    """Re-apply protection after a Specctra round trip rebuilds the tracks."""
    count = 0
    for item in board.GetTracks():
        if isinstance(item, pcbnew.PCB_VIA):
            x, y = mm(item.GetPosition())
            key = ("via", round(x, 3), round(y, 3))
        else:
            key = _seg_key(*mm(item.GetStart()), *mm(item.GetEnd()),
                           item.GetLayer())
        if key in PROTECTED:
            item.SetLocked(True)
            count += 1
    return count


def add_track(board, net, x0, y0, x1, y1, layer, width, protect=False):
    if x0 == x1 and y0 == y1:
        return None
    if protect:
        PROTECTED.add(_seg_key(x0, y0, x1, y1, layer))
    track = pcbnew.PCB_TRACK(board)
    track.SetStart(vec(x0, y0))
    track.SetEnd(vec(x1, y1))
    track.SetLayer(layer)
    track.SetWidth(pcbnew.FromMM(width))
    track.SetNet(net)
    board.Add(track)
    return track


def add_via(board, net, x, y, protect=False):
    if protect:
        PROTECTED.add(("via", round(x, 3), round(y, 3)))
    via = pcbnew.PCB_VIA(board)
    via.SetPosition(vec(x, y))
    via.SetFrontWidth(pcbnew.FromMM(VIA_SIZE))
    via.SetWidth(pcbnew.F_Cu, pcbnew.FromMM(VIA_SIZE))
    via.SetWidth(pcbnew.B_Cu, pcbnew.FromMM(VIA_SIZE))
    via.SetDrill(pcbnew.FromMM(VIA_DRILL))
    via.SetViaType(pcbnew.VIATYPE_THROUGH)
    via.SetLayerPair(pcbnew.F_Cu, pcbnew.B_Cu)
    via.SetNet(net)
    board.Add(via)
    return via


def clear_copper(board, tracks=True):
    # Delete, not Remove. KiCad 10 SWIG marks vias as owned after a
    # previous SaveBoard/LoadBoard, and Remove then trips thisown.
    if tracks:
        for item in list(board.GetTracks()):
            board.Delete(item)
    for zone in list(board.Zones()):
        board.Delete(zone)


def tie_u2_ep(board):
    """Belt and braces for the ES8311 exposed pad.

    Pad 21 now has an EP pin in PSV.kicad_sym, so the netlist carries it and
    generate_pcb.py assigns it. Re-assert it here so an older board file still
    lands on AGND instead of floating.
    """
    agnd = net_of(board, "/Audio/AGND")
    for fp in board.GetFootprints():
        if fp.GetReference() != "U2":
            continue
        for pad in fp.Pads():
            if pad.GetNumber() == "21" and pad.GetNetCode() != agnd.GetNetCode():
                pad.SetNet(agnd)
                print("  tied U2 pad 21 to AGND")
            return


def tie_mk1_ring(board):
    """Connect MK1's ring pad to the AGND pour.

    Pad 5 is the 0.32 mm ring around the 0.8 mm sound port. The AGND pour
    keeps ZONE_CLEARANCE off that hole and never reaches the ring. Pad 4
    is GND and sits in the pour; pad 3 is OUT− and must stay off AGND.
    A short stub from pad 4 is the electrical path to the ring.
    Freerouting leaves MK1-4 to MK1-5 open.
    """
    mk1 = board.FindFootprintByReference("MK1")
    if mk1 is None:
        return
    pads = {pad.GetNumber(): pad for pad in mk1.Pads()}
    if "4" not in pads or "5" not in pads:
        return
    agnd = net_of(board, "/Audio/AGND")
    x0, y0 = pad_xy(pads["5"])
    x1, y1 = pad_xy(pads["4"])
    add_track(board, agnd, x0, y0, x1, y1, pcbnew.F_Cu, DEFAULT_WIDTH, protect=True)


def tie_u1_edge_gnd(board, obstacles):
    """Via out U1 pad 63 before USB and fanout can box it.

    That castellation sits on the module's north-west corner. The locked USB
    pair and the I2S fanout vias later occupy every 2 mm seat around it, and
    DRC then reports an F.Cu GND sliver. A locked stub now keeps the pad on
    the plane.
    """
    fp = board.FindFootprintByReference("U1")
    if fp is None:
        return
    gnd = net_of(board, "GND")
    for pad in fp.Pads():
        if pad.GetNumber() == "63":
            pad.SetLocalZoneConnection(pcbnew.ZONE_CONNECTION_INHERITED)
            x, y = pad_xy(pad)
            stitch_one(board, obstacles, gnd, x, y, protect=True)
            return


def add_inner_planes(board, half_w, half_h):
    """The two solid planes. These are what GND and VDD33 pads via down to."""
    add_rect_zone(board, net_of(board, "GND"), pcbnew.In1_Cu,
                  -half_w, -half_h, half_w, half_h, "GND_In1", 0)
    add_rect_zone(board, net_of(board, "VDD33"), pcbnew.In2_Cu,
                  -half_w, -half_h, half_w, half_h, "VDD33_In2", 0)


def add_outer_pours(board, half_w, half_h):
    gnd = net_of(board, "GND")
    vdd = net_of(board, "VDD33")
    agnd = net_of(board, "/Audio/AGND")
    ax0, ay0, ax1, ay1 = ANALOG
    add_rect_zone(board, gnd, pcbnew.B_Cu, -half_w, -half_h, half_w, half_h, "GND_B", 0)
    add_rect_zone(board, gnd, pcbnew.F_Cu, -half_w, -half_h, half_w, half_h, "GND_F", 0)
    # Higher priority, so the digital F.Cu GND pour keeps out of the island.
    add_rect_zone(board, agnd, pcbnew.F_Cu, ax0, ay0, ax1, ay1, "AGND_F", 2)
    for x0, y0, x1, y1, name in VDD33_ISLANDS:
        add_rect_zone(board, vdd, pcbnew.F_Cu, x0, y0, x1, y1, name, 4)


def fill_zones(board):
    pcbnew.ZONE_FILLER(board).Fill(board.Zones())


# ---------------------------------------------------------------------------
# Geometry
# ---------------------------------------------------------------------------


def seg_point_dist(x0, y0, x1, y1, px, py):
    dx, dy = x1 - x0, y1 - y0
    length2 = dx * dx + dy * dy
    if length2 == 0:
        return math.hypot(px - x0, py - y0)
    t = max(0.0, min(1.0, ((px - x0) * dx + (py - y0) * dy) / length2))
    return math.hypot(px - (x0 + t * dx), py - (y0 + t * dy))


def seg_seg_dist(ax0, ay0, ax1, ay1, bx0, by0, bx1, by1):
    def cross(ox, oy, px, py, qx, qy):
        return (px - ox) * (qy - oy) - (py - oy) * (qx - ox)

    d1 = cross(bx0, by0, bx1, by1, ax0, ay0)
    d2 = cross(bx0, by0, bx1, by1, ax1, ay1)
    d3 = cross(ax0, ay0, ax1, ay1, bx0, by0)
    d4 = cross(ax0, ay0, ax1, ay1, bx1, by1)
    if ((d1 > 0) != (d2 > 0)) and ((d3 > 0) != (d4 > 0)):
        return 0.0
    return min(
        seg_point_dist(bx0, by0, bx1, by1, ax0, ay0),
        seg_point_dist(bx0, by0, bx1, by1, ax1, ay1),
        seg_point_dist(ax0, ay0, ax1, ay1, bx0, by0),
        seg_point_dist(ax0, ay0, ax1, ay1, bx1, by1),
    )


def point_in_rect(px, py, rect):
    x0, y0, x1, y1 = rect
    return x0 <= px <= x1 and y0 <= py <= y1


def seg_rect_dist(ax0, ay0, ax1, ay1, rect):
    if point_in_rect(ax0, ay0, rect) or point_in_rect(ax1, ay1, rect):
        return 0.0
    x0, y0, x1, y1 = rect
    edges = (
        (x0, y0, x1, y0),
        (x1, y0, x1, y1),
        (x1, y1, x0, y1),
        (x0, y1, x0, y0),
    )
    return min(seg_seg_dist(ax0, ay0, ax1, ay1, *e) for e in edges)


def pad_rect(pad):
    """Axis-aligned copper extent of a pad, in mm.

    GetBoundingBox() already accounts for footprint rotation, which the old
    width/height test did not: R2/R3 and every side-pin QFN pad are rotated,
    and an unrotated size test let stitch stubs graze them.
    """
    box = pad.GetBoundingBox()
    return (
        pcbnew.ToMM(box.GetLeft()),
        pcbnew.ToMM(box.GetTop()),
        pcbnew.ToMM(box.GetRight()),
        pcbnew.ToMM(box.GetBottom()),
    )


# ---------------------------------------------------------------------------
# Obstacle test for new copper
# ---------------------------------------------------------------------------


class Obstacles:
    """Everything a new via or track has to stay clear of.

    Layer aware. A B.Cu track is not in an F.Cu track's way, and only the
    drilled part of a through-hole obstructs every layer at once.
    """

    def __init__(self, board, half_w, half_h):
        self.half_w = half_w
        self.half_h = half_h
        self.pads = []      # (rect, netcode, layerset)
        self.holes = []     # (x, y, radius)
        self.tracks = []    # (x0, y0, x1, y1, half_width, netcode, layer)
        self.vias = []      # (x, y, radius, drill_radius, netcode)
        for fp in board.GetFootprints():
            for pad in fp.Pads():
                x, y = pad_xy(pad)
                drill = pcbnew.ToMM(pad.GetDrillSizeX())
                if drill > 0:
                    self.holes.append((x, y, drill / 2.0,
                                       -1 if is_npth(pad) else pad.GetNetCode()))
                if is_npth(pad):
                    continue
                layers = frozenset(pad.GetLayerSet().CuStack())
                self.pads.append((pad_rect(pad), pad.GetNetCode(), layers))
        for item in board.GetTracks():
            if isinstance(item, pcbnew.PCB_VIA):
                x, y = mm(item.GetPosition())
                self.vias.append((x, y, pcbnew.ToMM(via_width(item)) / 2.0,
                                  pcbnew.ToMM(item.GetDrill()) / 2.0,
                                  item.GetNetCode()))
                continue
            x0, y0 = mm(item.GetStart())
            x1, y1 = mm(item.GetEnd())
            self.tracks.append((x0, y0, x1, y1,
                                pcbnew.ToMM(item.GetWidth()) / 2.0,
                                item.GetNetCode(), item.GetLayer()))

    # -- incremental updates so a caller can place copper and keep testing --

    def add_via(self, x, y, netcode):
        self.vias.append((x, y, VIA_SIZE / 2.0, VIA_DRILL / 2.0, netcode))
        self.holes.append((x, y, VIA_DRILL / 2.0, netcode))

    def add_track(self, x0, y0, x1, y1, width, netcode, layer=pcbnew.F_Cu):
        self.tracks.append((x0, y0, x1, y1, width / 2.0, netcode, layer))

    def has_via_near(self, x, y, netcode, radius):
        """Is this pad already stitched? Keeps re-runs from stacking barrels."""
        for vx, vy, _vr, _vdr, vnet in self.vias:
            if vnet == netcode and math.hypot(x - vx, y - vy) <= radius:
                return True
        return False

    def in_bounds(self, x, y, margin):
        return abs(x) <= self.half_w - margin and abs(y) <= self.half_h - margin

    def via_fits(self, x, y, netcode):
        return self.track_fits(x, y, x, y, VIA_SIZE, netcode, layer=None)

    def track_fits(self, x0, y0, x1, y1, width, netcode, layer=pcbnew.F_Cu):
        """Clearance test for a whole segment, not just its endpoints.

        ``layer=None`` means a through-hole via: it has copper on every layer
        and a barrel that has to respect hole-to-hole everywhere.
        """
        half = width / 2.0
        drill_r = VIA_DRILL / 2.0 if layer is None else 0.0
        if not self.in_bounds(x0, y0, EDGE_CLEAR + half):
            return False
        if not self.in_bounds(x1, y1, EDGE_CLEAR + half):
            return False
        for hx, hy, hr, hnet in self.holes:
            d = seg_point_dist(x0, y0, x1, y1, hx, hy)
            if drill_r and d < drill_r + hr + HOLE_TO_HOLE:
                return False
            if hnet != netcode and d < half + hr + HOLE_CLEARANCE:
                return False
        for rect, pnet, layers in self.pads:
            if pnet == netcode:
                continue
            if layer is not None and layer not in layers:
                continue
            d = seg_rect_dist(x0, y0, x1, y1, rect)
            if d < half + CLEARANCE:
                return False
            if drill_r and d < drill_r + HOLE_CLEARANCE:
                return False
        for tx0, ty0, tx1, ty1, tw, tnet, tlayer in self.tracks:
            if tnet == netcode:
                continue
            if layer is not None and layer != tlayer:
                continue
            d = seg_seg_dist(x0, y0, x1, y1, tx0, ty0, tx1, ty1)
            if d < half + tw + CLEARANCE:
                return False
            if drill_r and d < drill_r + tw + HOLE_CLEARANCE:
                return False
        for vx, vy, vr, vdr, vnet in self.vias:
            d = seg_point_dist(x0, y0, x1, y1, vx, vy)
            if drill_r and d < drill_r + vdr + HOLE_TO_HOLE:
                return False
            if vnet == netcode:
                continue
            if d < half + vr + CLEARANCE:
                return False
            if d < half + vdr + HOLE_CLEARANCE:
                return False
        return True


# ---------------------------------------------------------------------------
# Fallback maze router
# ---------------------------------------------------------------------------
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

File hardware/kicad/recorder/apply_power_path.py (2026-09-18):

#!/usr/bin/env python
"""Apply the BQ24074 power-path island to the existing routed board.

Loads recorder.kicad_pcb, does not wipe copper. Replaces U3, drops J4/D3
if they are still on the board, adds the charger programming resistors,
retargets load copper from VBAT to VSYS, fans the QFN out, then re-pours
and repairs. Run with KiCad 10 python.exe.

Do not wipe the USB-edge box: F1, C4 and the VBUS vias have to stay.
"""

from __future__ import annotations

import json
import math
import os
import sys

import pcbnew

try:
    import wx
except ImportError:
    wx = None
else:
    wx.DisableAsserts()

from generate_pcb import (
    NO_BOM,
    NO_PICK_AND_PLACE,
    PLACEMENT,
    SUBSTITUTIONS,
    load_netlist,
    resolve_footprint,
    vec,
)
from route_pcb import (
    PCB,
    PLACEMENT as PLACEMENT_JSON,
    DEFAULT_WIDTH,
    MazeRouter,
    Obstacles,
    POWER_WIDTH,
    add_track,
    add_via,
    apply_board_rules,
    drc_json,
    fill_zones,
    finish,
    hop_bcu,
    mm,
    net_of,
    pad_of,
    pad_xy,
    repair_unconnected,
    save,
    stage_repair,
    stitch_orphan_gnd_pads,
    update_placement_open_items,
    via_in_zone,
    _lock,
    _place_via,
    _try_widths,
)

os.environ.setdefault("PSV_ROUTE_SKIP_LOCK", "1")

DELETE_REFS = ("J4", "D3")
REPLACE_REFS = ("U3",)
MOVED_REFS = ("C5", "R4")
NEW_REFS = ("R8", "R9", "R10", "R11")
U3_BOX = (21.5, -42.0, 27.0, -36.5)
CHARGER_NETS = {
    "CHG_STAT",
    "VBUS_CHG",
    "VBAT",
    "VSYS",
    "/Power/PROG",
    "PROG",
    "/Power/ISET",
    "/Power/ILIM",
    "/Power/TMR",
    "/Power/TS",
    "/Power/ITERM",
    "/Power/CHG_LED",
}


def ensure_net(board, name):
    info = board.FindNet(name)
    if info is None or info.GetNetCode() <= 0:
        board.Add(pcbnew.NETINFO_ITEM(board, name))
        board.BuildListOfNets()
        info = board.FindNet(name)
    return info


def netmap(board, names):
    out = {}
    for name in names:
        out[name] = ensure_net(board, name)
    return out


def fp_by_ref(board):
    return {fp.GetReference(): fp for fp in board.GetFootprints()}


def place_one(board, ref, comp, pad_nets, nets):
    x, y, rot, _note = PLACEMENT[ref]
    fp, _fpid, _sub = resolve_footprint(comp["footprint"])
    fp.SetReference(ref)
    fp.SetValue(comp["value"])
    fp.SetField("Datasheet", "~")
    fp.SetPosition(vec(x, y))
    if rot:
        fp.SetOrientationDegrees(rot)
    fp.SetPath(pcbnew.KIID_PATH())
    fp.SetExcludedFromBOM(ref in NO_BOM)
    fp.SetExcludedFromPosFiles(ref in NO_PICK_AND_PLACE)
    for pad in fp.Pads():
        name = pad_nets.get((ref, pad.GetNumber()))
        if name and name in nets:
            pad.SetNet(nets[name])
    board.Add(fp)
    return fp


def assign_pads(board, pad_nets, nets):
    for fp in board.GetFootprints():
        ref = fp.GetReference()
        for pad in fp.Pads():
            name = pad_nets.get((ref, pad.GetNumber()))
            if name and name in nets:
                pad.SetNet(nets[name])


def near_xy(x, y, tx, ty, r):
    return math.hypot(x - tx, y - ty) <= r


def near_battery(x, y):
    return near_xy(x, y, -16.0, 34.0, 10.0) or near_xy(x, y, -16.0, 26.0, 6.0)


def track_xy(item):
    if isinstance(item, pcbnew.PCB_VIA):
        x, y = mm(item.GetPosition())
        return x, y, x, y
    x0, y0 = mm(item.GetStart())
    x1, y1 = mm(item.GetEnd())
    return x0, y0, x1, y1


def touches_fp(item, fp, slop=0.4):
    x0, y0, x1, y1 = track_xy(item)
    for pad in fp.Pads():
        box = pad.GetBoundingBox()
        left = pcbnew.ToMM(box.GetLeft()) - slop
        top = pcbnew.ToMM(box.GetTop()) - slop
        right = pcbnew.ToMM(box.GetRight()) + slop
        bottom = pcbnew.ToMM(box.GetBottom()) + slop
        if (left <= x0 <= right and top <= y0 <= bottom) or (
            left <= x1 <= right and top <= y1 <= bottom
        ):
            return True
    return False


def delete_items(board, items):
    for item in items:
        board.Delete(item)
    return len(items)


def in_box(x, y, box):
    x0, y0, x1, y1 = box
    return x0 <= x <= x1 and y0 <= y <= y1


def copper_surgery(board, doomed_fps):
    doomed = []
    vsys = ensure_net(board, "VSYS")
    for item in list(board.GetTracks()):
        name = item.GetNetname()
        x0, y0, x1, y1 = track_xy(item)
        if name in {"WALL_5V", "/Power/PROG", "PROG"}:
            doomed.append(item)
            continue
        if any(touches_fp(item, fp) for fp in doomed_fps):
            doomed.append(item)
            continue
        if name in CHARGER_NETS and (
            in_box(x0, y0, U3_BOX) or in_box(x1, y1, U3_BOX)
        ):
            if name == "VBAT" and (near_battery(x0, y0) or near_battery(x1, y1)):
                continue
            doomed.append(item)
            continue
        if not isinstance(item, pcbnew.PCB_VIA):
            if math.hypot(x1 - x0, y1 - y0) < 0.08 and name in CHARGER_NETS:
                doomed.append(item)
                continue
        if name == "VSYS" and (
            near_xy(x0, y0, -16.95, -28.775, 0.4)
            or near_xy(x1, y1, -16.95, -28.775, 0.4)
        ):
            doomed.append(item)
            continue
        if name != "VBAT":
            continue
        if item.IsLocked():
            continue
        start_bat = near_battery(x0, y0)
        end_bat = near_battery(x1, y1)
        if start_bat and end_bat:
            continue
        if not start_bat and not end_bat:
            item.SetNet(vsys)
            continue
        doomed.append(item)
    return delete_items(board, doomed)


def drop_via_crowding_iset(board):
    """HEAD parked a locked GND stitch where ISET now sits."""
    dropped = 0
    for item in list(board.GetTracks()):
        if not isinstance(item, pcbnew.PCB_VIA):
            continue
        x, y = mm(item.GetPosition())
        if math.hypot(x - 16.64, y + 34.3) < 0.4:
            board.Delete(item)
            dropped += 1
    return dropped
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

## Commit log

2026-09-01 Add the first snapshot of the Pixel snap voice-note recorder.
    The hardware, firmware, and host-sim work already live in this tree.
    [audio.kicad_sch, case.scad, envelope.scad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]
2026-09-02 Add Cloud Agent dev environment (host sim, ngspice, KiCad 10)
2026-09-06 Add KiStack KiCad skills for Cursor agents
    Vendor American-Embedded/kistack skills into .cursor/skills so later
    Cloud Agents get schematic, PCB, BOM, export, and Gerber workflows.
2026-09-06 Route the recorder board and make the fab package match it
    The board had planes but no signals. It now carries 694 traces and 193
    vias from freerouting, driven headless through Specctra DSN/SES, with the
    USB pair, the ES8311 fanout and the analog island hand-routed first and
    locked so rip-up cannot cut them.
    kicad-cli pcb drc now reports zero violations at every severity and zero
    unconnected items.
    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
    [audio.kicad_sch, io.kicad_sch, mcu_usb.kicad_sch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]
2026-09-06 Route USB as a real pair and ground the USB-C shell
    The autorouter sent D+ on a 16.6 mm diagonal across B.Cu. B.Cu is the face
    that lies against the phone and is otherwise a solid GND pour, so that
    slotted the shield and ran a USB line straight at the handset.
    U1's USB pads sit on the module's top row, the far side of a 15.9 mm
    module from J2, and the castellations leave 0.05 mm between pads, so the
    pair cannot cross the footprint. It now goes up the 3.3 mm channel
    between J1 and U1 in two lanes 0.4 mm apart. Both nets already surface
    west of J2 on their own link, so extending those links west drops each
    into its lane with no crossing anywhere on the board. U7 hangs off the
    lanes as a short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
    [mcu_usb.kicad_sch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]
2026-09-06 Update the docs to the board that now exists
    Six files still told a reader, and a fab, things that stopped being true:
    - AGENTS.md said signals were still open. They are routed.
    - hardware/kicad/README.md, docs/manufacturing.md and fab/README.md all
    specified ~90 ohm USB. Ordering controlled impedance for a pair we
    deliberately left uncontrolled costs money and proves nothing, so each
    now says so plainly and points at the reasoning.
    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
    [recorder-B_Courtyard.gbr, recorder-B_Cu.gbl, recorder-B_Fab.gbr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]
2026-09-06 Check the board against JLCPCB capability instead of house numbers
    The DRC floors in the project were a mix of round numbers and values
    relaxed until the board passed. Some were looser than the fab: nothing
    enforced JLC's 0.45 mm pad hole-to-hole spacing or their 0.5 mm minimum
    non-plated hole, and silk text was allowed down to 0.8 mm, which is only
    legal on their high-precision legend line.
    Every rule now carries the JLC figure it came from and says where it is
    deliberately tighter. Hole-to-copper goes to 0.3 mm because non-plated
    holes carry a +/-0.2 mm diameter tolerance, so a 1.7 mm mounting hole can
    come back 0.1 mm larger in radius and eat JLC's 0.2 mm minimum. The two
    checks that dep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
    [generate_pcb.py]
2026-09-06 Open MK1's land pattern up around the sound port
    The stock Infineon land leaves 0.18 mm of copper to the 0.8 mm acoustic
    port and its custom-pad anchor circle leaves 0.25 mm. JLC needs 0.20 mm,
    and a non-plated hole can drill 0.1 mm oversize in radius, so both would
    let the drill cut into the seal ring. An open solder ring leaks and costs
    low-frequency response, which is the one thing this part exists for.
    The ring and its stencil aperture move out to r=0.95 mm and the anchor
    circle shrinks to 0.32 mm so it sits wholly inside the annulus instead of
    poking toward the hole. Closest copper is now 0.32 mm and the ring stays
    closed. The port itself is unchanged: the datasheet asks for 0.8 mm and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
2026-09-06 Make the board answer for itself: parity, library names, stale pours
    Three things the gate could not see.
    Every footprint on the board carried a bare name like C_0805_2012Metric
    while the schematic asked for Capacitor_SMD:C_0805_2012Metric, because
    FootprintLoad takes a directory and stamps what it returns with the bare
    name. That is 57 footprint_symbol_mismatch hits under --schematic-parity,
    and it means nothing on the board was traceable to a library. Qualifying
    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
2026-09-06 Rebuild the board and the fab package against the tightened rules
    Applies the rule, footprint and parity changes to recorder.kicad_pcb:
    silk re-seated at 1.0 mm, pours backed off the mounting-hole barrels to
    0.3 mm, MK1's ring pad opened up, library-qualified footprint names, and
    two redundant vias dropped next to J1 and J2 pads. 695 tracks, 185 vias,
    8 zones.
    kicad-cli pcb drc: 0 violations at every severity, 0 unconnected. The 27
    remaining --schematic-parity notes are all expected and now recorded in
    placement.json: 22 module pads with no schematic pin (spare ESP32-S3 GPIO
    castellations, NC pins, the USB-C SBU pair), the 4 mounting holes, which
    are mechanical and have no symbol, and SP1's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
    [recorder-B_Courtyard.gbr, recorder-B_Cu.gbl, recorder-B_Fab.gbr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]
2026-09-06 Document what the board now holds against what JLC allows
    Records the capability table (0.15 mm tracks, 0.6/0.3 vias, 0.62 mm pad
    hole spacing, 0.3 mm hole-to-copper, standard-font silk) so the order
    options are unambiguous: nothing here should trigger a fine-line,
    small-via or high-precision-legend surcharge, and impedance control is
    still deliberately off. Also notes MK1's adapted land and why parity is
    27 rather than 0.
2026-09-12 Give fp-lib-table one owner so editing the schematic stops deleting it
    generate_pcb.py listed every library the board cites; generate_recorder.py
    then overwrote the same file with a PSV-only table. Whichever ran last won,
    so the documented way to edit the schematic silently dropped thirteen rows
    and left every non-PSV land unresolvable, which DRC only calls a warning.
    Both generators now call fp_lib_table.write_fp_lib_table(), which rediscovers
    the set from the placed symbols in every sheet plus the board on disk. Run
    order no longer changes the answer. The scan skips the (lib_symbols) cache,
    whose stock defaults name libraries this project never places.
    Also merge rather than replace the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
    [fp_lib_table.py, generate_pcb.py, generate_recorder.py]
2026-09-12 Fail the ship gate on warnings and on parity notes nobody expected
    The gate ran DRC at --severity-all but then only exited on errors and
    unconnected items. Everything this board is actually checked against at
    warning severity went through: silk over copper, dangling vias, missing
    footprint libraries, and the JLC 0.45 mm pad hole-spacing rule in
    recorder.kicad_dru. A via parked at that spacing, the exact drill-tolerance
    miss the previous commit removed, would have been printed and then shipped.
    It now fails on any violation. A rule this project decides not to care about
    belongs in rule_severities in recorder.kicad_pro set to 'ignore', where the
    decision is a reviewable diff.
    route_pcb.py had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
    [check_gates.py, route_pcb.py]
2026-09-12 Stop keeping two hand-typed copies of the USB pair geometry
    placement.json and params.json each carried their own prose description of
    D+/D-. Only params.json was ever updated, so placement.json still claimed a
    0.15 mm gap pair under 20 mm long at 70 ohm while the board carries a 0.4 mm
    pitch pair near 75 ohm. placement.json is what the next agent reads as
    placement truth, so that copy was the one most likely to be acted on.
    route_pcb.py now copies the note from params.json when it refreshes the file,
    and the note no longer quotes lengths: params.json said 45.8 mm on D+ while
    the board measures 59.6 mm of copper on that net. The measured numbers come
    from the board in routing.usb, which now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
2026-09-12 Check that placement.json still describes the board
    AGENTS.md calls placement.json and recorder.kicad_pcb twins, and nothing
    enforced it. placement.json is what the CAD side and the next agent read as
    placement truth, so when the board moved ahead of it the drift stayed
    invisible until someone cut a case wall against the old number.
    check_placement.py now compares the two part by part on footprint, XY,
    rotation and layer, and reports anything on the board that placement.json
    does not list, anything listed that is not on the board, and any field that
    disagrees.
    [check_placement.py]
2026-09-12 Swap SW1 for a side-actuated switch so the case needs no lever
    The record button is on the left long wall, but SW1 was a top-actuated
    PTS645: the plunger pointed at the phone, not at the wall. Every version of
    that ends in a moulded lever inside a 9 mm stack, pivoting a sideways press
    into a downward one, with the travel budget of a 3D print.
    Panasonic EVQP7C01P instead. Side push, SPST, 3.5 x 2.9 x 1.35 mm, 2.2 N,
    0.2 mm travel, reflow, JLCPCB C388883 and in stock. KiCad 10 already ships
    the land as Button_Switch_SMD:SW_SPST_EVQP7C, and its two moulded bosses
    drop into 0.7 mm NPTH holes that take the sideways load instead of the
    solder joints. Rotated 270 and pushed out to x = -29.3, the a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
    [case.scad, io.kicad_sch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]
2026-09-12 Generate the JLCPCB BOM and CPL from the board
    docs/manufacturing.md tells you to upload hardware/kicad/jlcpcb_bom.csv and
    jlcpcb_cpl.csv beside the Gerbers. Both were typed by hand, so a wrong row
    there is not documentation drift, it is a misassembled board. They had
    drifted. C11, C12, C17 and C18 still carried the coordinates and the zero
    rotation they had before the codec decoupling was re-placed, up to 10 mm and
    a quarter turn away from where the copper is. BT1's land had been renamed
    under the BOM, MK1's too, and SW1 named the switch that was replaced in the
    previous commit. Nothing compared either file to recorder.kicad_pcb.
    generate_jlc.py writes both, in the same check_gates.py pass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
    [jlcpcb_bom.csv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]
2026-09-12 Delete the last hand-typed copy of the USB pair lengths
    The previous pass took these numbers out of params.json and left
    placement.json, written from the board by route_pcb.py, as the one place
    they live. This sentence in hardware/kicad/README.md was a third copy and it
    was missed: 45.8 mm on D+, 44.2 mm on D-, dating from before the reroute.
    The reasoning around it is still right, so only the millimetres go.
2026-09-12 Hold pad hole spacing at 0.6 mm in DRC, not at the fab reject line
    The dru comment already said designed spacing has to beat JLC's 0.45 mm pad
    hole-to-hole floor by the plated-hole tolerance, and to aim for 0.6 mm. The
    rule itself was still (min 0.45mm). KiCad treats that as inclusive, so a via
    whose hole wall sat exactly 0.45 mm from a PTH pad was legal, never became a
    warning, and the ship gate — which now fails on every warning — still plotted.
    0.45 + 0.13 mm plated-hole tolerance is 0.58 mm; the min is that number
    rounded to 0.6 mm. The board's closest pad-involved pair is 0.618 mm (J2's
    NPTH board lock to a VBUS via), so the copper does not move. A planted via
    at 0.50 mm from J1 pa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
2026-09-12 Say the pad-spacing DRC floor is 0.6 mm, and refuse a stale pos file
    AGENTS.md still listed the dru check as "0.45 mm pad hole-to-hole". That is
    JLC's fab floor. The rule itself is 0.6 mm, so the sentence was the same
    kind of leftover the last review already caught.
    generate_jlc.py only compared the set of references in recorder-pos.csv to
    the board. Same refs at last week's coordinates would have rewritten the
    pick-and-place file and not noticed. It now compares X, flipped Y and
    rotation too. A 1 mm shift of C11 in an otherwise matching pos file now
    exits instead of writing.
    [generate_jlc.py]
2026-09-12 Name the dru pad-spacing floor 0.6 mm in the KiCad README too
    The capability table still lists JLC's 0.45 mm. The sentence that described
    the rule file itself still said 0.45 mm, which is the leftover AGENTS.md
    had.
2026-09-12 Refuse a pos file that flips a part onto the other face
    write_cpl already compared X, flipped Y and rotation. Side was still
    copied through unread, so a stale export that put SW1 on bottom at the
    same XY would have rewritten the pick-and-place file onto the phone face.
    Every part on this board is top, so it was not live, but the check is the
    same comparison and a flipped Side now exits.
    [generate_jlc.py]
2026-09-13 Pick a JLCPCB-placeable KELIKING speaker for SP1
    The 15x11 placeholder could not go on the SMT line. The KLJ-01304T land, shifted pouch, and lid grille let JLC place C18186315 on a DRC-clean board.
    [audio.kicad_sch, case.scad, jlcpcb_bom.csv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]
2026-09-14 Drop the lid fence 2 mm so it misses the speaker
    check_envelope was looking at the 40×30 pouch, so it printed ok while the
    printed wall sat 0.7 mm from the 4 mm can and overlapped it in height.
    The pocket moves to y=10. The check now models that fence, twins SP1 XY
    to placement.json, and fails the old y=12 geometry.
    [case.scad, params.scad]
2026-09-16 Swap in a BQ24074 power-path charger so USB can run the board with the pouch unplugged.
    [audio.kicad_sch, jlcpcb_bom.csv, power.kicad_sch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]
2026-09-16 Add SMT Boot and Reset buttons so the board can enter download mode after USB mass-storage owns the port.
    [jlcpcb_bom.csv, mcu_usb.kicad_sch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]
2026-09-16 Put the real JST-PH on BT1, add a BAT ceramic at U3, and document lid-off Boot/Reset.
    The power-path PR still shipped a 7.8 mm solder-wire land while the BOM
    named S2B-PH-K-S. Owner chose the real 2.00 mm connector: pad 1 stays at
    (-23.5, 34) on VBAT so the existing B.Cu hop still hits it, pad 2 moves
    to (-21.5, 34) on GND. C21 is 10 µF next to U3 BAT for USB with the pouch
    unplugged. The 6.0 mm housing does not fit the 5.45 mm lid cavity, so the
    case cuts a window through shell_back. Boot and Reset stay lid-off; a
    flush hole would not reach the 5 mm actuators. power_path.cir now runs
    USB-with-BT1-open and pouch-only through a BATFET.
    [case.scad, params.scad, power.kicad_sch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]
2026-09-16 Refresh Gerbers and JLCPCB CSVs after the JST-PH land change.
    check_gates rewrote the fab package from the live board. BT1 is now
    JST_PH_S2B-PH-K next to C173752, C21 is on the CPL, and DRC is still
    0/0 with 27 expected parity notes.
    [jlcpcb_bom.csv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]
2026-09-18 Give every board part an LCSC number so JLCPCB will assemble it.
    Blank LCSC cells were skipping the passives, the analog LDO, the load switch, the 12.288 MHz oscillator, the MEMS mic, and the UART header. A missing code now fails the generator instead of writing an empty cell.
    [jlcpcb_bom.csv]
2026-09-18 Keep J1 off SMT and fix MK1 pinout plus the 2.8 V analog rail.
    J1 is a vertical 1x4 that will not fit under the lid, and the tails poke
    toward the phone. Flag it exclude_from_bom so JLCPCB does not wave-solder
    it. Keep C124378 in docs/bom.md and write jlcpcb_extra.csv so the header
    can still be ordered as loose extra parts.
    IM73A135 pin 3 is OUT-, a ~250 ohm amplifier output, not GND. Leave it
    open; C15 still AC-couples OUT+ and C16 still takes codec MIC_N to AGND.
    U8 is now LP5907-2.8 (C186700) because the capsule VDD abs max is 3.0 V.
    ES8311 AVDD is 1.7-3.6 V and Y1 is 1.71-3.63 V, so the analog island can
    sit at 2.8 V. Digital IO stays on VDD33.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
    [audio.kicad_sch, mcu_usb.kicad_sch, power.kicad_sch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]
2026-09-18 Refresh Gerbers after lifting MK1 OUT- off AGND.
    The leftover AGND stub next to pad 3 was 0.04 mm from the open OUT-
    pad. That stub is gone. DRC is clean at every severity. Assembly BOM
    drops J1 (62 parts); jlcpcb_extra.csv still lists C124378 so the
    header can be ordered loose.
    [jlcpcb_bom.csv, jlcpcb_extra.csv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]
2026-09-18 Record the three JLCPCB order-time LCSC swaps.
    F1 C37010 is not a catalog part. U7 C8678 is an SMA Schottky, not the
    USB ESD chip. Y1 C1857159 was a SMT shortfall. The order uses C883095,
    C7519, and C49207908 on the same lands.
    [jlcpcb_bom.csv]
2026-09-19 Drop the 3.3 V Lucki can as a Y1 backup.
    Y1 runs from 3V3A at 2.8 V. Lucki C5917271 is specified at 3.3 V only
    (2.97 V minimum), so it is not a substitute. Keep the ordered JLYE
    C49207908, which is 1.8–3.3 V CMOS on the same ASE land.
2026-09-19 Run the JLC order-code lock without importing pcbnew.
    The test now reads bom.md and the generated CSV itself, and check_gates
    calls it with the other plain-Python checks so a later LCSC revert fails
    the gate.
    [check_gates.py, test_jlc_order_codes.py]
2026-10-25 Compact 62 x 88 spin with Wi-Fi share, and drop the Cursor-only setup
    Hardware, firmware and CAD work for the compact-final board:
    - 62 x 88 x 10.65 mm envelope: magnetic 4-pin pad J2 replaces USB-C,
    speaker and PA removed, board and lid spun 180 degrees on the tray.
    - Rerouted recorder.kicad_pcb and regenerated the fab outputs from it.
    - New footprints for J2, the SD NAND, and the pouch pigtail land.
    - Firmware Wi-Fi share (SoftAP, file page, read-only WebDAV) plus a
    Korvo prove overlay in sdkconfig.korvo_wifi_share.
    - Tray with blind magnet wells, metal-tray STEP export, DFM check,
    case viewer and renders.
    Tool-neutral agent setup:
    - Skills moved from .cursor/skills to .claude/skill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
2026-10-31 Refresh board, BOM stock, renders, and tooling
